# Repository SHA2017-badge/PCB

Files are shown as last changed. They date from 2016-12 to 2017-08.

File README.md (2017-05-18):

# PCB
This repository hosts the board files for the SHA2017 badge. There are a couple different revisions:
* _rev0_0_1_: First dev board
* _rev0_0_2_: First dev board with fixed IO error (not produced)
* _rev0_1_0_: "Pre-badge"
* _rev1_0_0_: Semi-final badge design - via under D3 shorts VCC to GND (oops)
* _rev1_0_1_: FINAL Badge design with short fixed and silkscreen art

The badge is designed in Eagle version 6.6.

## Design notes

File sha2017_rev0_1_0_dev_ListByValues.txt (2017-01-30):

Qty	Value	Part Num	Package	Parts
1		*	610X12243021	X2
1		68712414022	68712414022	X4
5	1k	ERJ-3GEYJ102V	R0603-DASHES	R3, R12, R14, R30, R34
9	1u	GRM188R61E105KA12D	C0603-DASHES	C18, C20, C24, C30, C31, C33, C34, C35, C36
1	2.2k	*	R0603-DASHES	R29
11	4u7/16V	GRM21BR61C475KA88K	C0805	C4, C8, C14, C16, C17, C19, C22, C25, C29, C32, C38
1	5R	ERJ-3GEYJ5R1V	R0603-DASHES	R19
18	10k	ERJ-3GEYJ103V	R0603-DASHES	R1, R4, R5, R8, R9, R10, R11, R13, R15, R16, R17, R18, R22, R25, R26, R27, R28, R33
1	22µ	NLCV32T-220K-EF	1210	L1
1	27R	*	R0603-DASHES	R2
3	100k	CRCW0603100KFKEA	R0603-DASHES	R6, R20, R31
22	100n	GRM188R71H104KA93D	C0603-DASHES	C1, C2, C3, C5, C6, C7, C9, C10, C11, C12, C13, C15, C21, C23, C26, C27, C28, C37, C39, C40, C41, C42
1	150k	*	R0603-DASHES	R32
2	220k	*	R0603-DASHES	R7, R21
2	470R	ERJ-3GEYJ103V	R0603-DASHES	R23, R24
2	500mA	0ZCJ0025FF2E	PTC-1206	F1, F2
1	2908-05WB-MG	2908-05WB-MG	MICRO-SD-SOCKET-PP	X1
1	AP7215	AP7215-33YG-13	SOT89	IC2
5	BAT20JFILM	BAT20JFILM	SOD-323	D2, D3, D7, D8, D9
1	CP210X_USB_UART	CP2102-GMR	MLP28	IC1
1	CPT112	*	QFN20-3X3MM	IC6
1	ESP32WROOM32	*	ESP32MOD	IC3
5	FIDUCIAL	NAP	FIDUCIAL_1MM	FD1, FD2, FD3, FD4, FD5
1	FXL6408	*	UMLP-16	IC5
1	JST-PH3	*	JST-PH3	X3
2	JUMPER-PAD-2-NOYES_SILK	NAP	PAD-JUMPER-2-NO_YES_SILK	SJ1, SJ2
1	MCP73833	*	MSOP-10	IC4
5	MMBT2222A	BC817-25,215	SOT23-3	Q2, Q3, Q4, Q5, Q7
1	MOLEX-47346-0001	10118194-0001LF	MOLEX-47364-0001	USB1
1	MOTOR10MM	*	VIBE-MOTOR-10MM	U$1
1	PMEG4005EJ	SD05-7	SOD-323	D1
1	RED	*	LED-0603	D5
1	SI1304 BDL	SI1308EDL-T1-GE3	SOT323	Q6
3	SI2301DS	*	SOT23	T1, T2, T3
6	SK6812	SK6812	WS2812B	D100, D101, D102, D103, D104, D105
2	SWITCH-MOMENTARY-2SMD	*	TACTILE-SWITCH-SMD	S1, S2
43	TEST-POINT3	NAP	PAD.03X.03	TP1, TP2, TP5, TP100, TP101, TP102, TP103, TP104, TP105, TP106, TP107, TP108, TP109, TP110, TP111, TP112, TP113, TP114, TP115, TP116, TP117, TP118, TP119, TP120, TP121, TP122, TP123, TP124, TP125, TP126, TP127, TP128, TP129, TP130, TP131, TP132, TP133, TP134, TP135, TP136, TP137, TP138, TP139
2	TOUCHROUND	NAP	TOUCH_BUTTON	TB103, TB104
2	TOUCHSELECT	NAP	TOUCH_SELECT	TB100, TB101
1	TOUCH_CROSS	NAP	TOUCH_CROSS	TB102
27	VIA	NAP	VIA	$$U$1, $$U$2, $$U$3, $$U$7, $$U$8, $$U$9, U$2, U$3, U$4, U$5, U$6, U$10, U$11, U$12, U$13, U$14, U$15, U$16, U$17, U$18, U$19, U$20, U$21, U$22, U$23, U$24, U$25
1	Yellow	*	LED-0603	D4
1	green	*	LED-0603	D6

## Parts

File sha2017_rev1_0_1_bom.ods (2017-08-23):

SHA2017 Badge BOM
 |  | rev1_0_1 | https://github.com/SHA2017-badge/PCB
 |  | Fixed C46 error
Qty per PCB | Type | Device | Value | Package | Parts
1 | ESP module | ESP32WROOM32 | ESP32WROOM32 | ESP32MOD | IC3
1 | Touch IC | MPR121QR2 | MPR121QR2 | QFN40P300X300X60-20N | U1
1 | Battery charger IC | TP4056 | TP4056 | SOP-8 | IC4
1 | Voltage regulator | AP2114H-3.3TRG1 | AP2114H-3.3TRG1 | SOT233-3 | IC2
1 | USB-Serial IC | CP210X_USB_UART | CP210X_USB_UART | MLP28 | IC1
1 | Battery connector | JST S3B-PH-SM4-TB | JST S3B-PH-SM4-TB | JST-PH3 | X4
5 | NPN transistor | TRANSISTOR_NPNMMBT2222A | MMBT2222A | SOT23-3 | Q1, Q2, Q3, Q4, Q6
3 | P-channel MOSFET | MOSFET-PCHANNEL |  | SOT23-3 | T1, T2, T3
1 | N-channel MOSFET | MOSFET-NCHANNEL2N7002PW | SI1304 BDL | SOT323 | Q5
2 | Tactile switch | SWITCH-MOMENTARY-2SMD | SWITCH-MOMENTARY-2SMD | TACTILE-SWITCH-SMD | S1, S2
1 | USB connector | MOLEX-47346-0001 | MOLEX-47346-0001 | MOLEX-47364-0001 | USB1
1 | IO Expansion header | 610X12243021 |  | 610X12243021 | X3
1 | Display socket | 68712414022 | 24 pos FPC 0.5mm SMD right angle | 68712414022 | X1
2 | PTC Fuse | PTCSMD | 1A | PTC-1206 | F1, F2
5 | Schottky diode | BAT20JFILM | NSVR0320MW2T1G | SOD-323 | D2, D3, D7, D8, D9
1 | ESD Suppressor | DIODE-SCHOTTKY-PMEG4005EJ | SD05-7 | SOD-323 | D1
1 | Red LED | LED0603 | RED | LED-0603 | D5
1 | Yellow LED | LED0603 | Yellow | LED-0603 | D4
1 | Green LED | LED0603 | green | LED-0603 | D6
1 | Inductor | INDUCTOR1210 | 47µ | L1210 | L1
23 | Capacitor | C0603 | 100n | C0603 | C1, C2, C3, C4, C5, C6, C7, C8, C11, C12, C14, C22, C23, C27, C31, C37, C40, C44, C45, C10, C16, C28, C29
11 | Capacitor | C0603 | 1µ | C0603 | C19, C21, C25, C32, C33, C35, C36, C38, C39, C42, C46
12 | Capacitor | C-EUC0805 | 4.7µ / 16V | C0805 | C9, C13, C15, C17, C18, C20, C24, C26, C30, C34, C41, C43
2 | Resistor | R0603 | 1.2k | R0603 | R29, R35
5 | Resistor | R0603 | 100k | R0603 | R1, R6, R20, R31, R36
16 | Resistor | R0603 | 10k | R0603 | R4, R5, R8, R9, R10, R11, R13, R15, R16, R17, R18, R25, R27, R28, R22, R32
1 | Resistor | R1206 | 0.27Ω 1/4W | R1206 | R30
3 | Resistor | R0603 | 1k | R0603 | R3, R12, R14
2 | Resistor | R0603 | 220k | R0603 | R7, R21
1 | Resistor | R1206 | 27Ω | R1206 | R2
2 | Resistor | R0603 | 4k7 | R0603 | R23, R24
1 | Resistor | R0603 | 2.7Ω | R0603 | R19
1 | Resistor | R0603 | 75k 1% | R0603 | R37
0 | Resistor | R0603 | 0Ω | R0603 | R26 | ! Only populate for GD display !
110
Optional
6 | SK2812 RGBW pixels | SK6812 | SK6812-RGBW | 5050 | D100, D101, D102, D103, D104, D105
1 | Micro SD socket | 2908-05WB-MG | 2908-05WB-MG | MICRO-SD-SOCKET-PP | X2
1 | Pager motor | MOTOR10MM | MOTOR10MM | VIBE-MOTOR-10MM | M1

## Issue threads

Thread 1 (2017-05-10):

Consider porting from ESPUSB

cnlohr, 2017-05-10:
Just throwing out the idea, though I haven't gotten around to porting ESPUSB to the ESP32, I have considered it.  Any interest in adding possible hardware support to your design?  You would only need to have two adjacent GPIO pins to add support.

gavanfantom, 2017-05-11:
That's a neat idea but unfortunately we're so close to the event now that we have had to feature-freeze the PCB already.

We do however have quite a lot of software work that needs doing between now and the end of July and while we do have a few people on the team, another person who is as familiar with the ESP32 as you are would be a real advantage. Would you be interested in lending a hand?

cnlohr, 2017-05-11:
Aah, gotcha.  Things are kinda insane for me, right now since I'm co-chairing MAGStock and that's June 8-11 then I have to worry about badges for MAGLabs (I think they're '8266 because of the stringent price requirements).  I will consider it after MAGStock though.

annejan, 2017-05-11:
Hi @cnlohr the adjacent IO16 and IO17 pins (as well as 12, 14 and 33, 3.3V and GND) are accessible through the expansion header :)
So using ESPUSB should be possible as-is . . right?

NiklasFauth, 2017-05-11:
I don't think ESPUSB is ported for the ESP32 yet. Shouldn't be a problem through.

cnlohr, 2017-05-11:
Hmm, I could see having a connector for it.  Would need a pull-up.  I have really wanted to develop full-speed USB 1.1 for the ESP32 for a while since I think it's possible.

van-cahall, 2017-05-31:
I'm not familiar with this badge, but ESPUSB for the ESP32 would be awesome!  USB is the only thing missing from the ESP32 for several killer projects I'd like to do.  +1

cnlohr, 2017-05-31:
Ughhhh.. I'm doing MAGStock prep now.  I think I'm going to put libsurvive on the backburner to give a stab at full-speed USB on the 32.

Low-speed "should" be a trivial change from the '8266.

zoutepopcorn, 2017-06-18:
Great job cnlohr :D.

cnlohr, 2017-06-19:
I'm actually doing a totally different approach ATM, but it's going well.  I would much rather get full-speed working over simply switching around low-speed.

nissimzur, 2017-07-01:
Can someone point me to SHA2017-badge schematics diagram?

annejan, 2017-07-01:
It's in this repository . .
https://github.com/SHA2017-badge/PCB/blob/master/sha2017_rev1_0_1_schematic.pdf should probably be what you are looking for.

nissimzur, 2017-07-01:
Thank you.

I offering my help in any hardware challenge you have around ESP8266/ESP32.

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

Closed 2017-05-11.

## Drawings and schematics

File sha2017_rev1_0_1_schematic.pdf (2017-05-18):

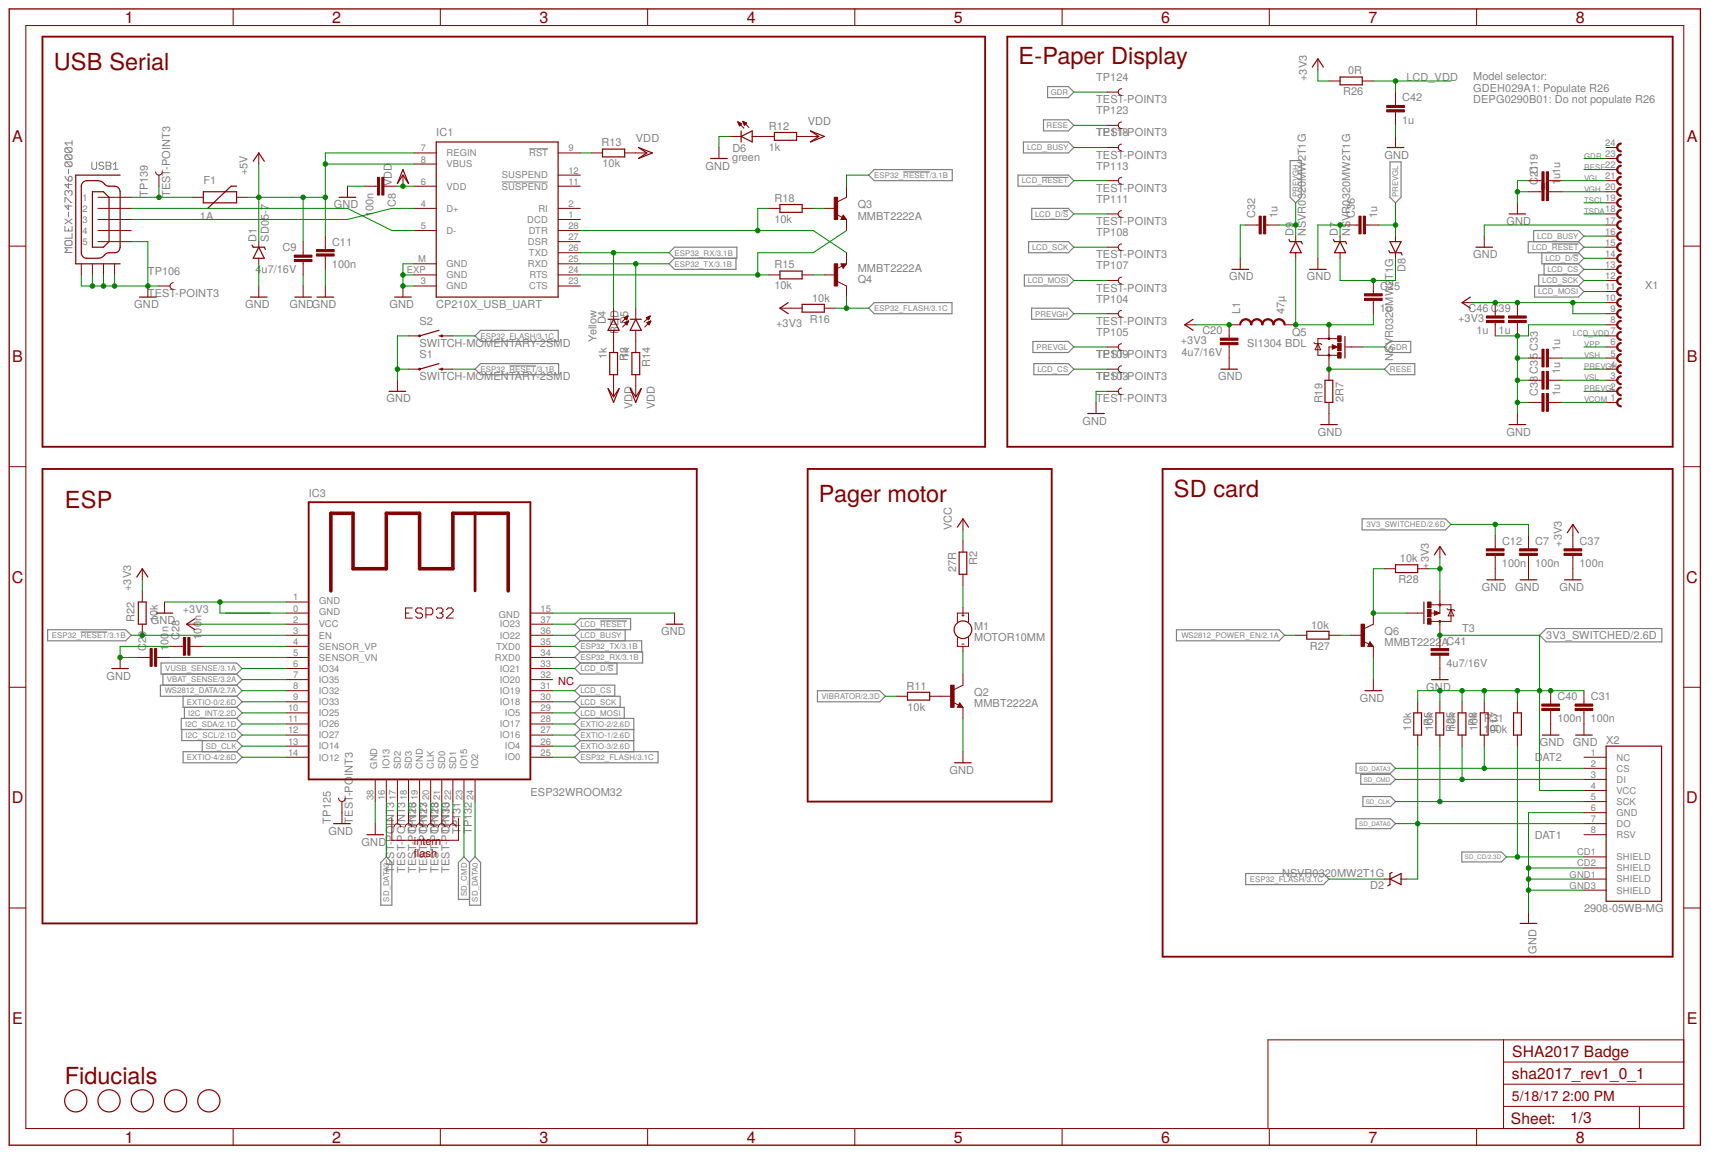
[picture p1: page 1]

+3V3 GND
TEST-POINT3 TEST-POINT3 TEST-POINT3 TEST-POINT3 TEST-POINT3 TEST-POINT3 TEST-POINT3 TEST-POINT3 TEST-POINT3 TEST-POINT3 TEST-POINT3 GND

Model selector: GDEH029A1: Populate R26 DEPG0290B01: Do not populate R26

TEST-POINT3 TEST-POINT3 TEST-POINT3 TEST-POINT3 TEST-POINT3 TEST-POINT3 TEST-POINT3 GND

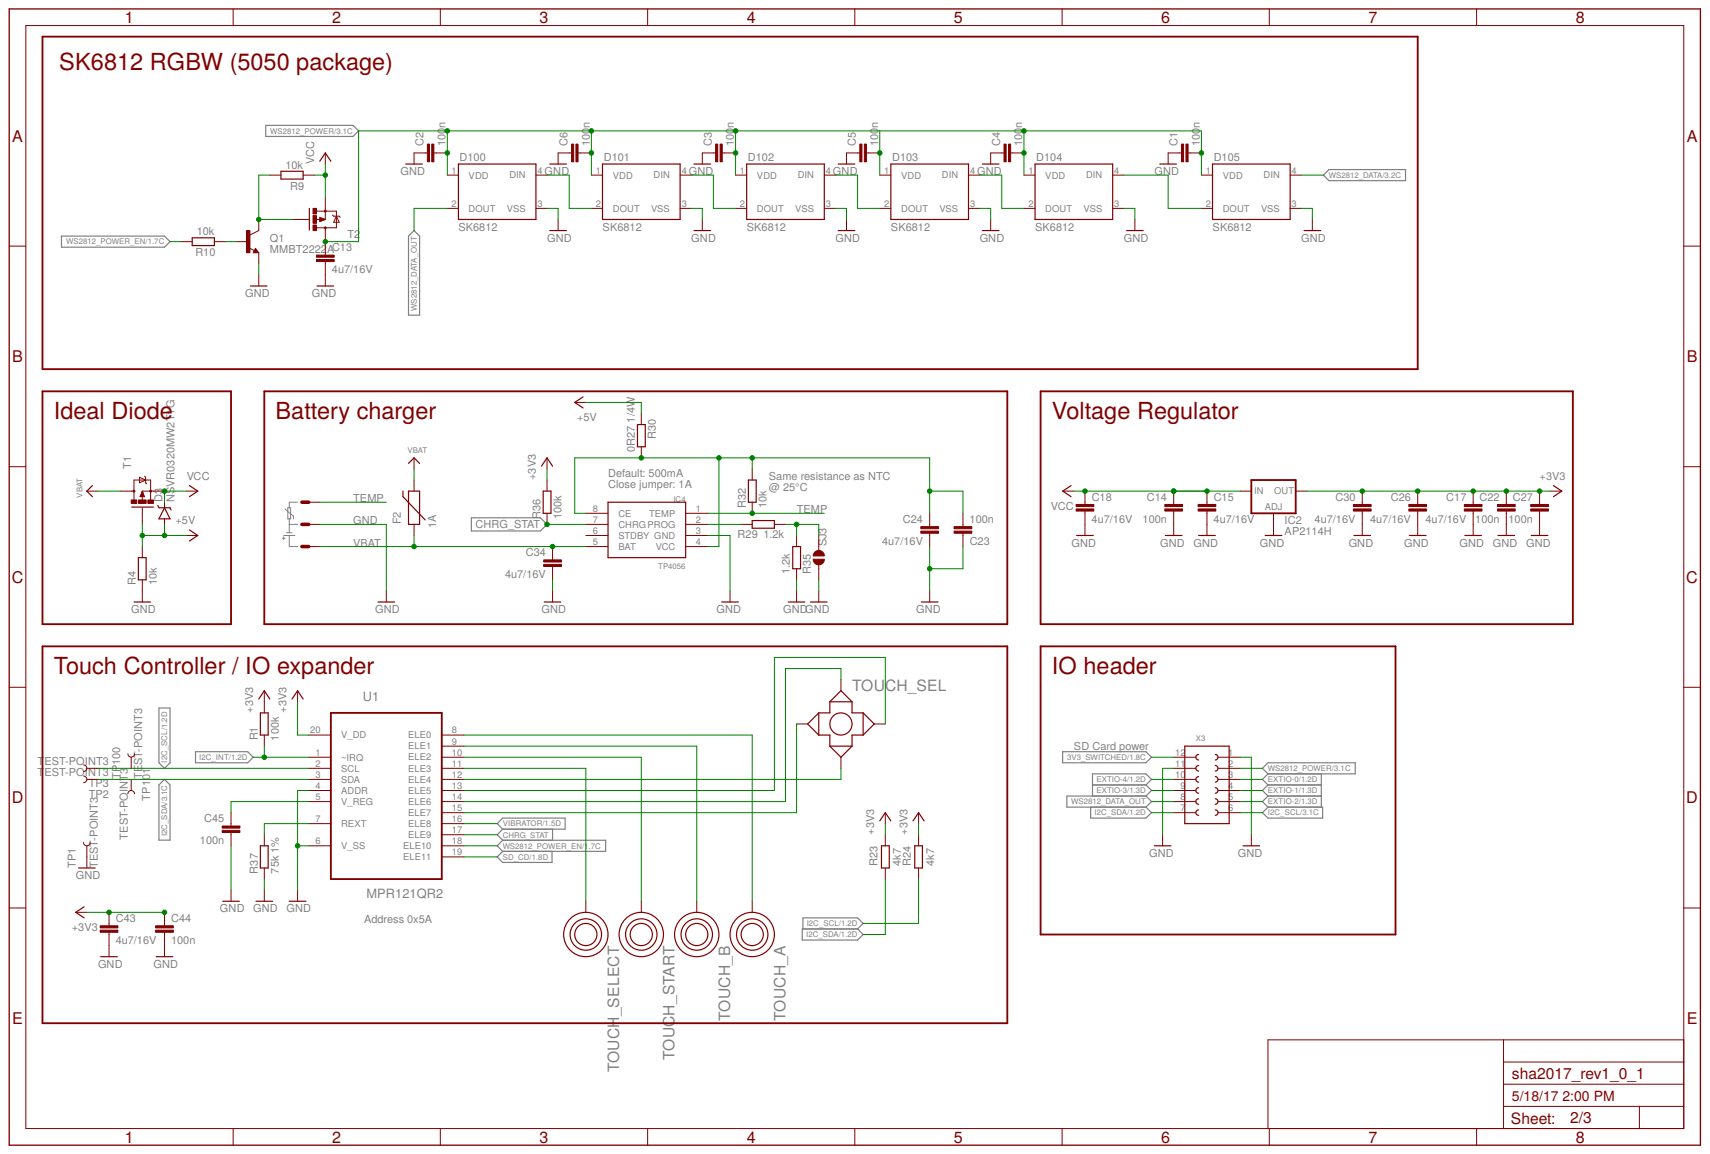
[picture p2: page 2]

Default: 500mA Close jumper: 1A GND
IN OUT C18 F2
TEMP

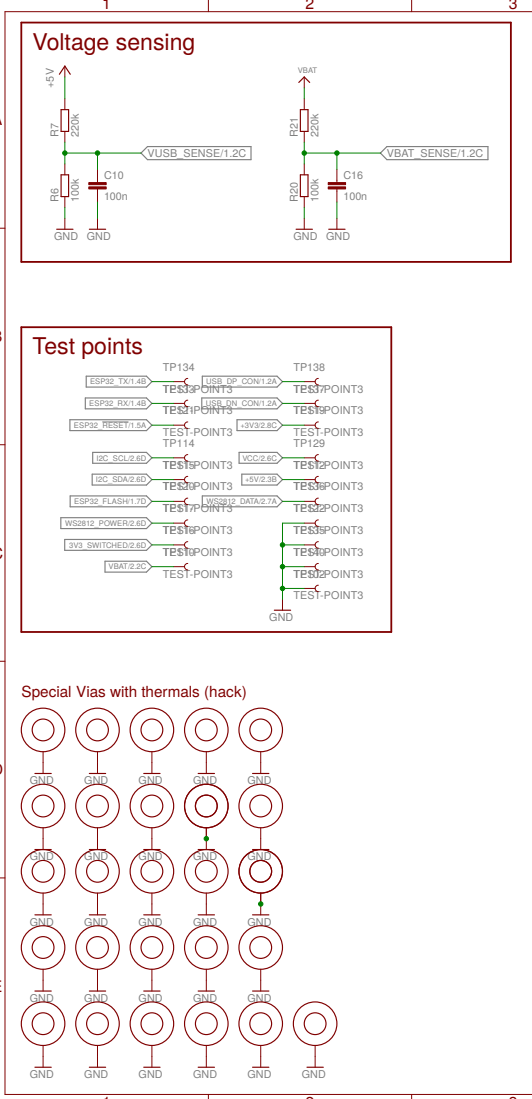
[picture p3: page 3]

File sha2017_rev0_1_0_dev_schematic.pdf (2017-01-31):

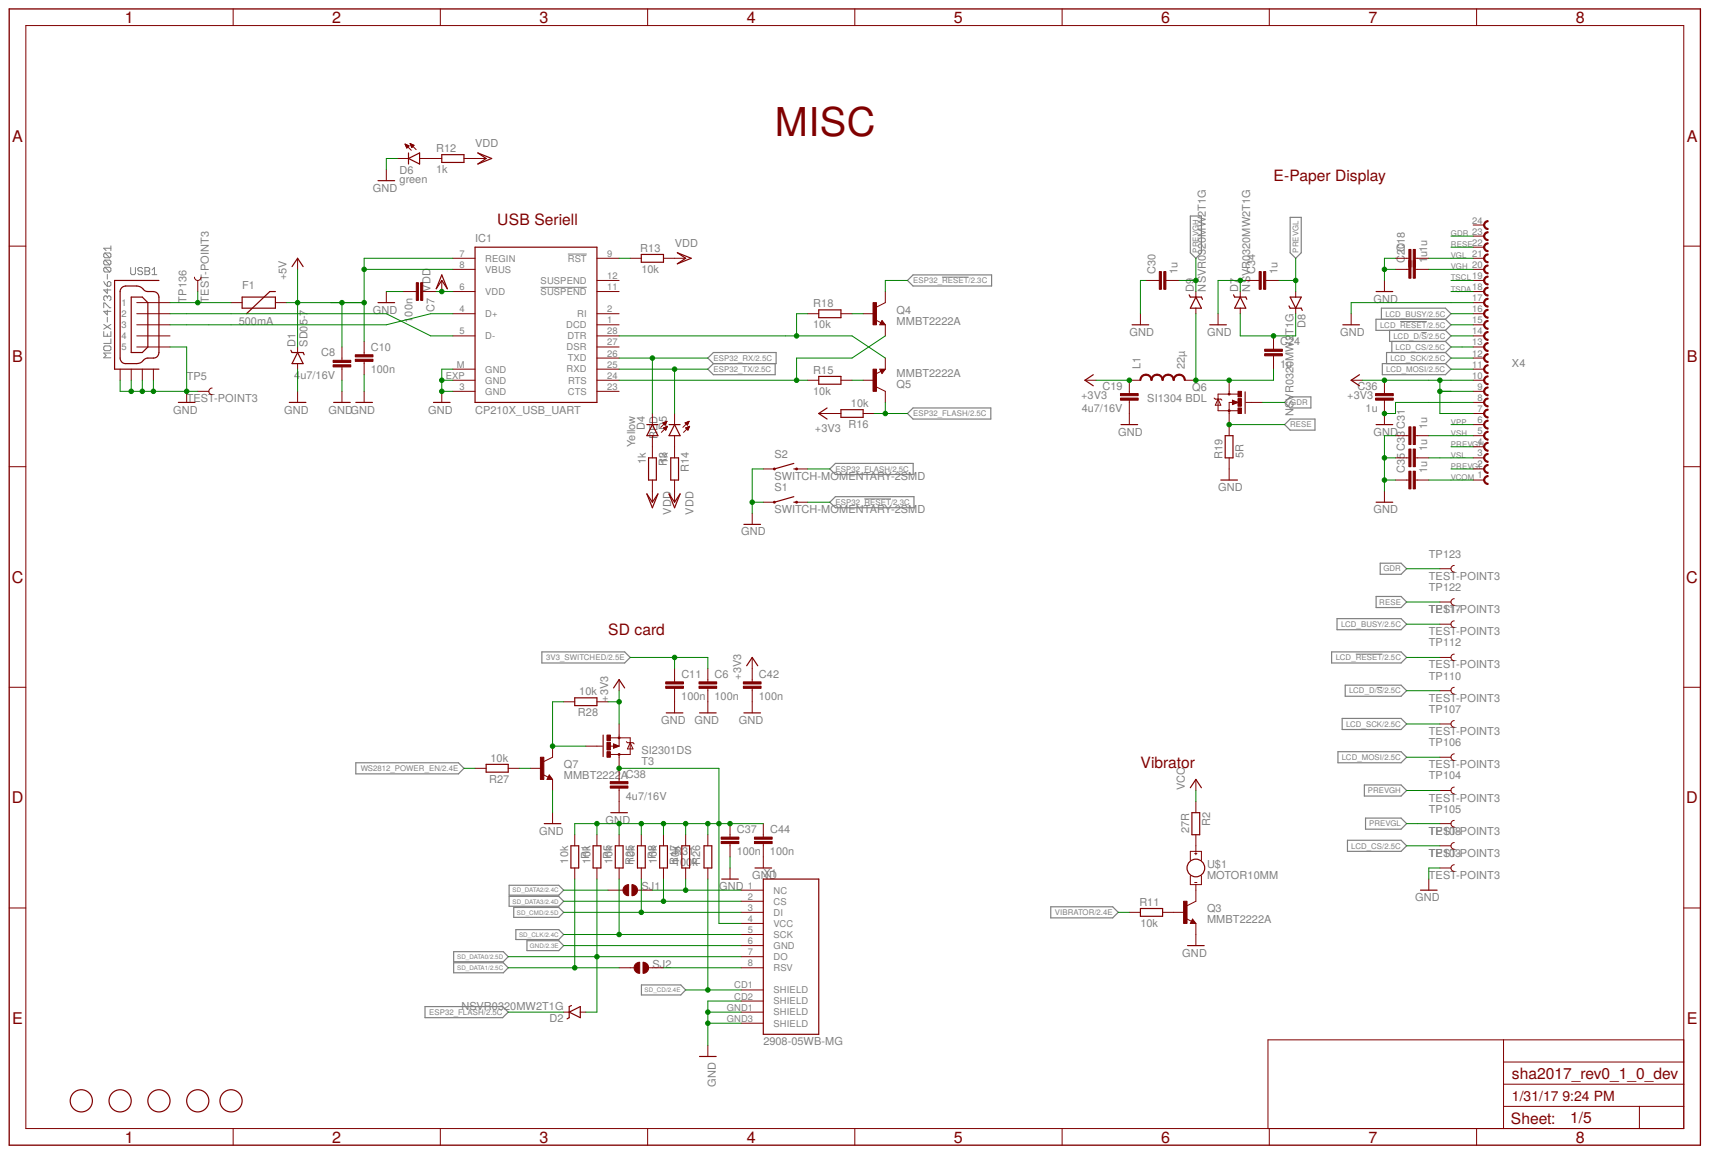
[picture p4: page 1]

SD_DATA0/2.5D | SJ2

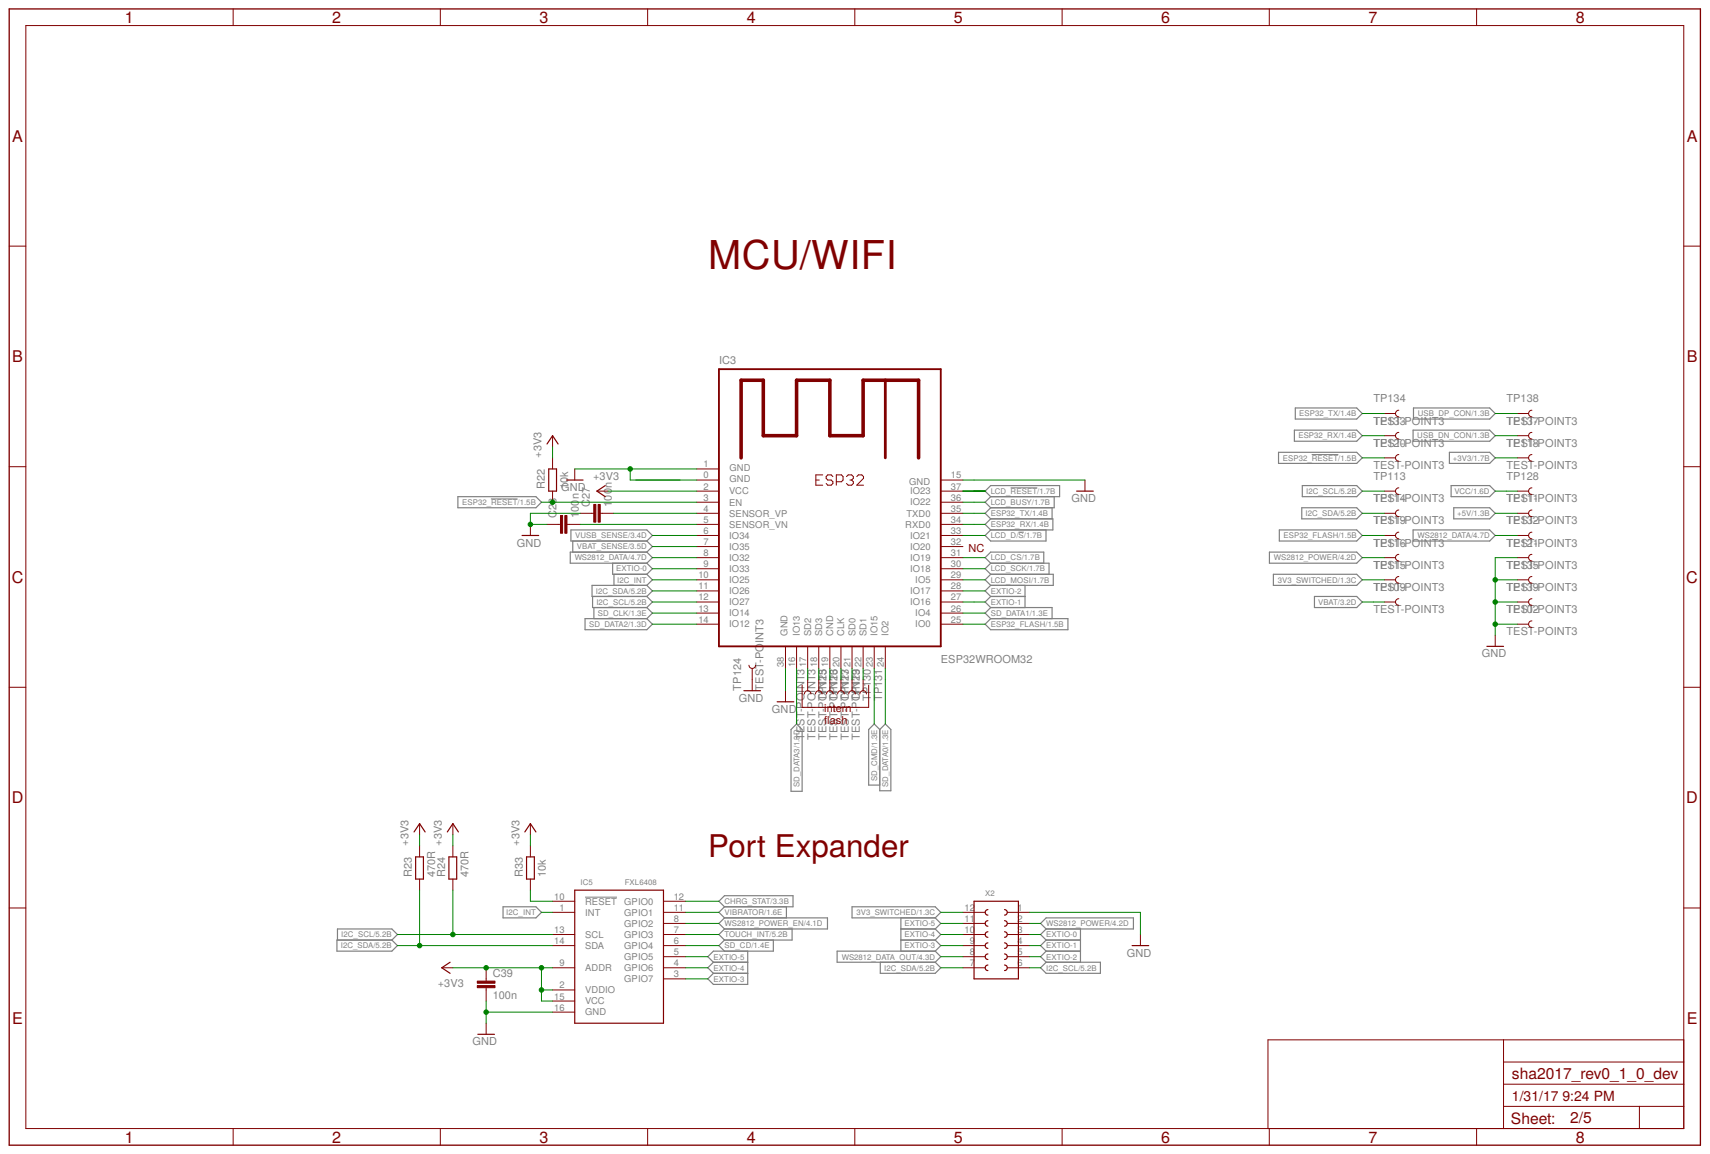
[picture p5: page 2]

TEST-POINT3 TEST-POINT3 TEST-POINT3 TEST-POINT3 TEST-POINT3 GND

TEST-POINT3 TEST-POINT3 TEST-POINT3

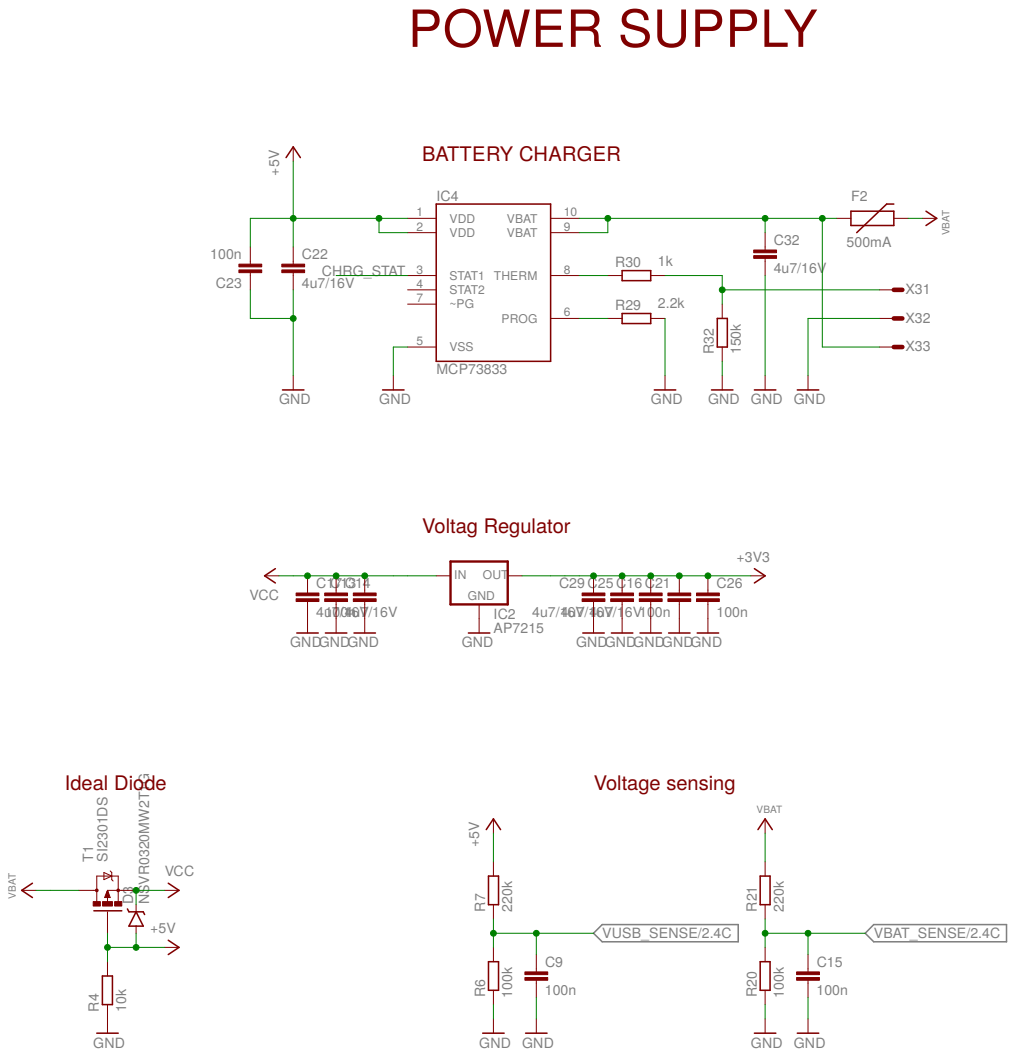
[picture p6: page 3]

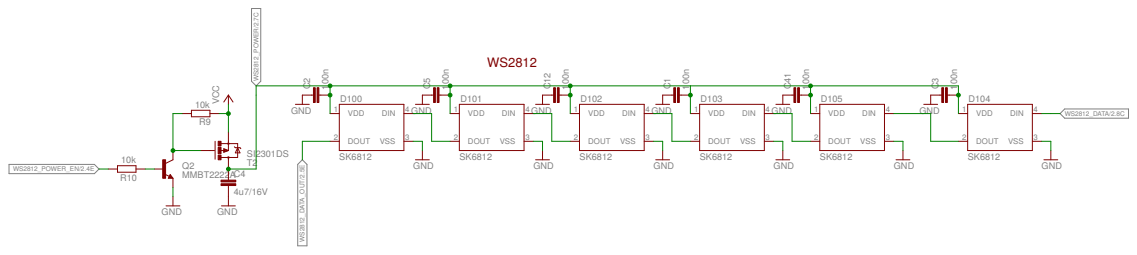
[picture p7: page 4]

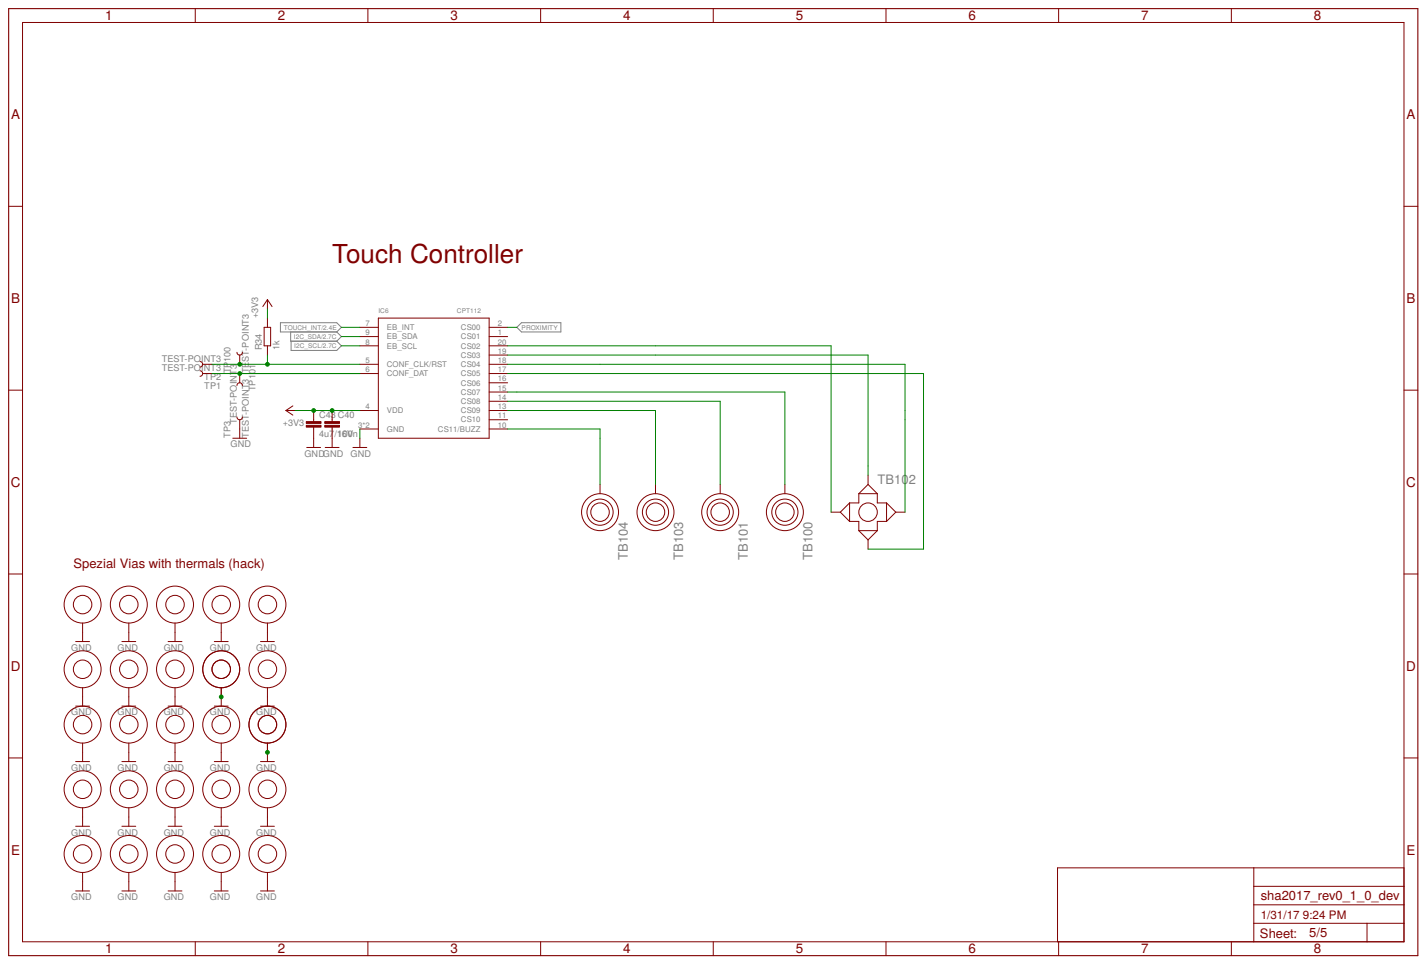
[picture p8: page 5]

TEST-POINT3 TEST-POINT3 TEST-POINT3 GND

18 CS05
17 CS06
16 CS07 15 CS08

Spezial Vias with thermals (hack)

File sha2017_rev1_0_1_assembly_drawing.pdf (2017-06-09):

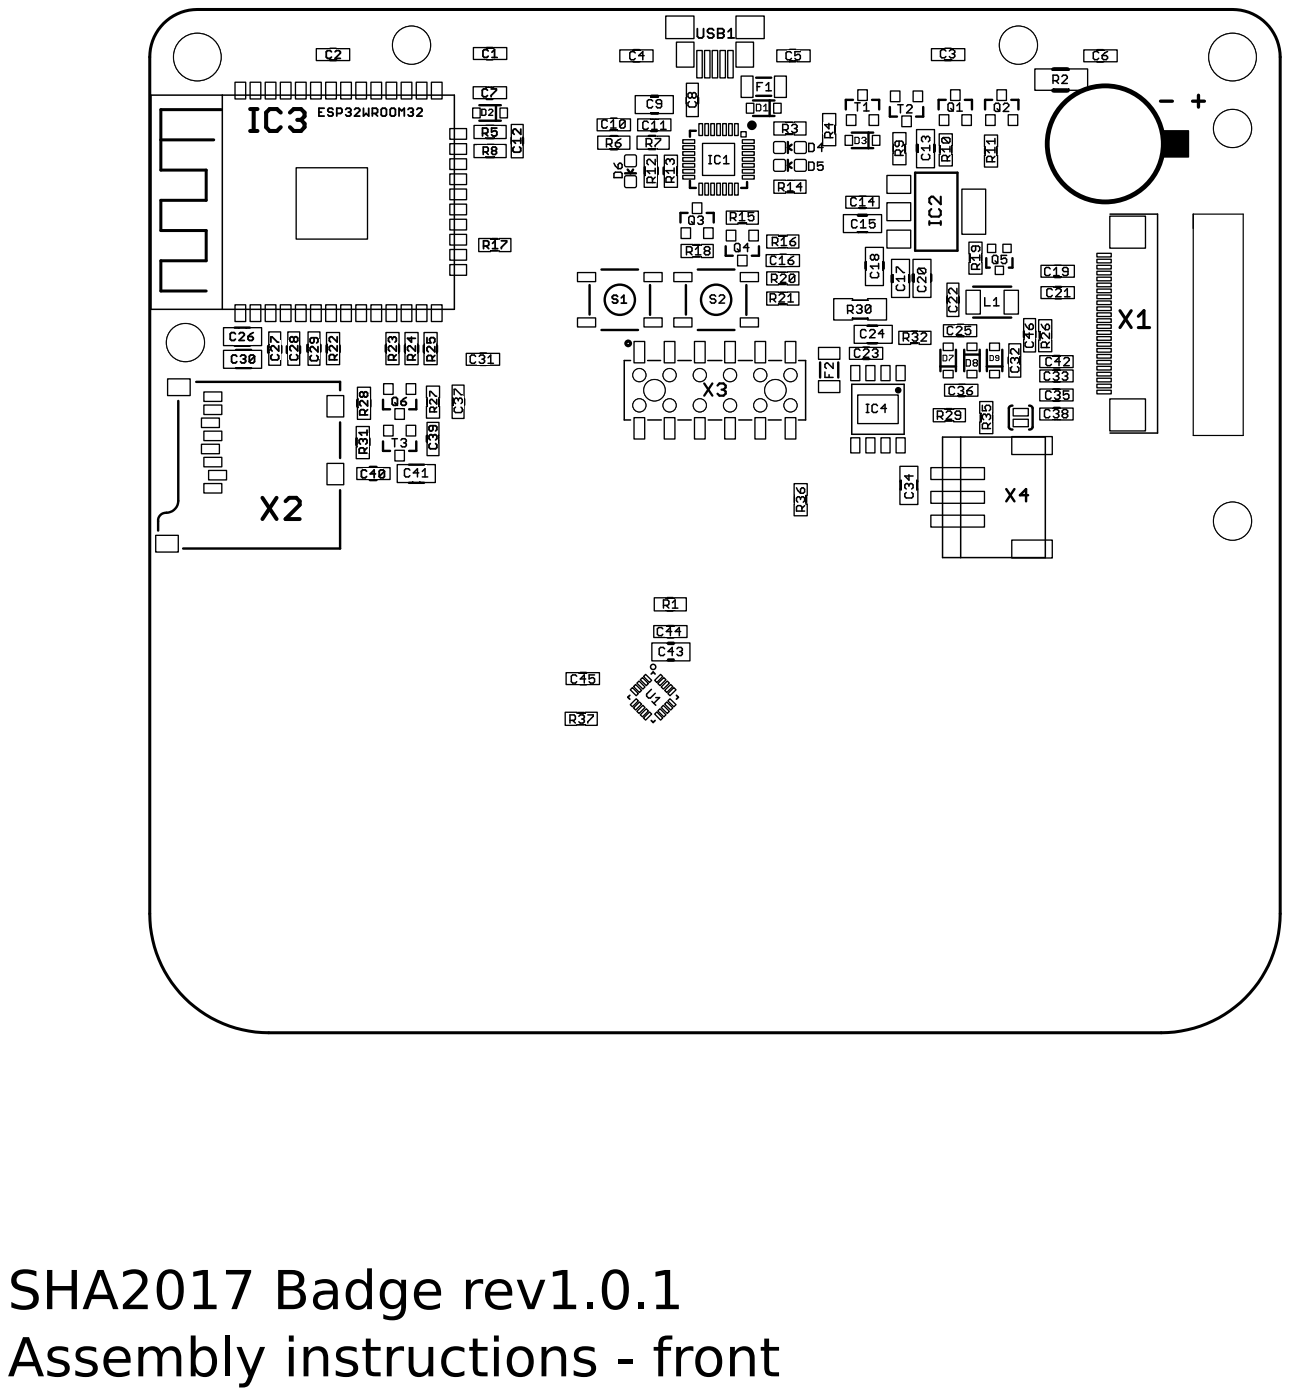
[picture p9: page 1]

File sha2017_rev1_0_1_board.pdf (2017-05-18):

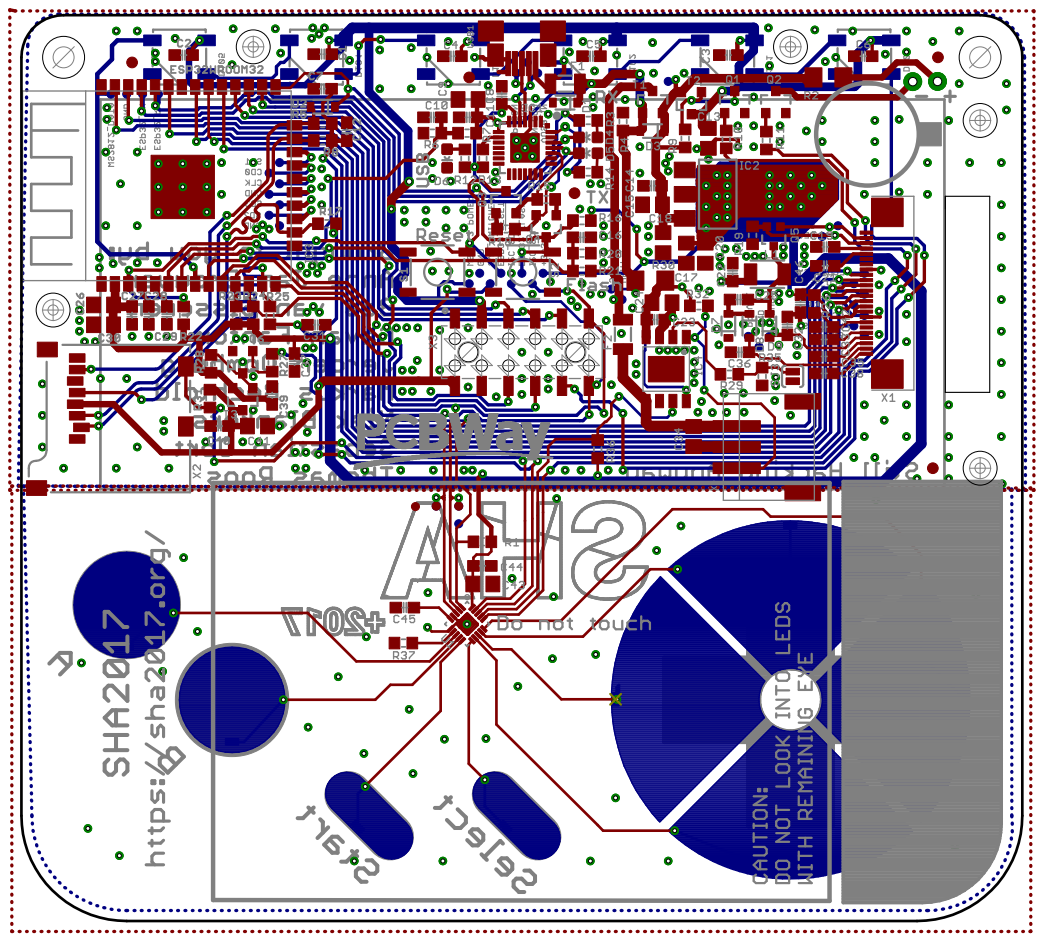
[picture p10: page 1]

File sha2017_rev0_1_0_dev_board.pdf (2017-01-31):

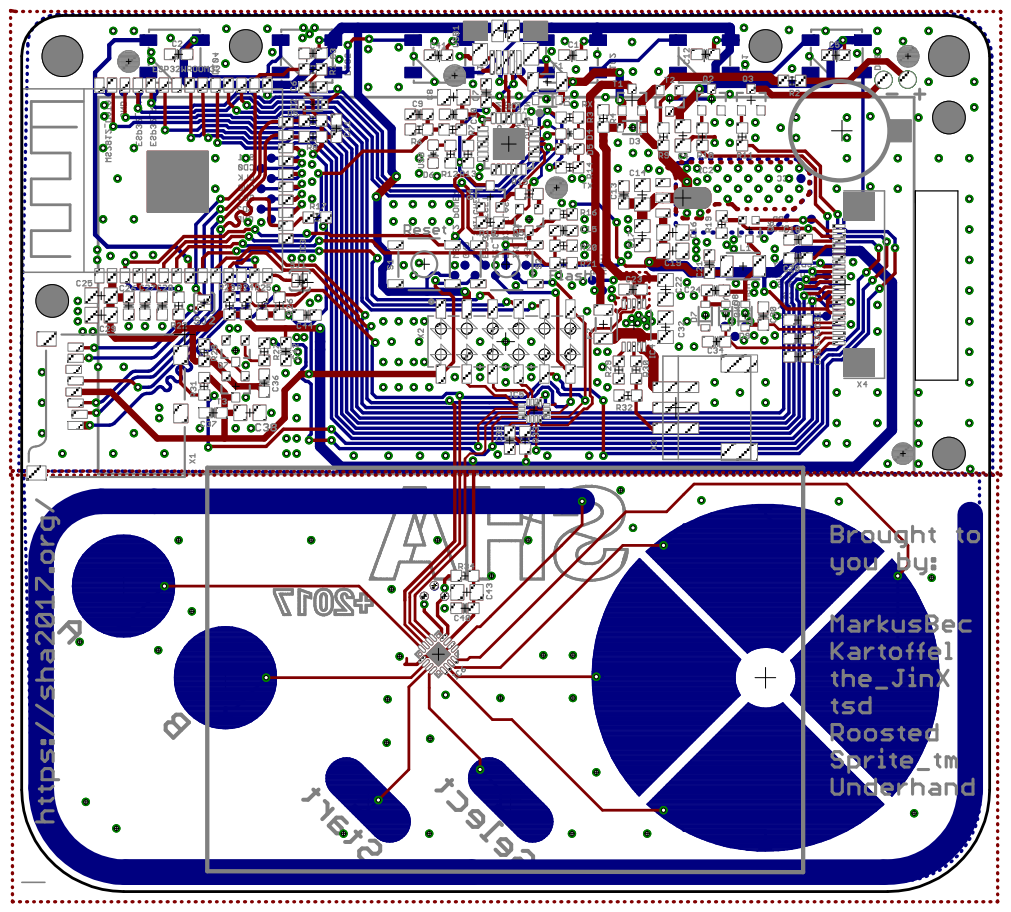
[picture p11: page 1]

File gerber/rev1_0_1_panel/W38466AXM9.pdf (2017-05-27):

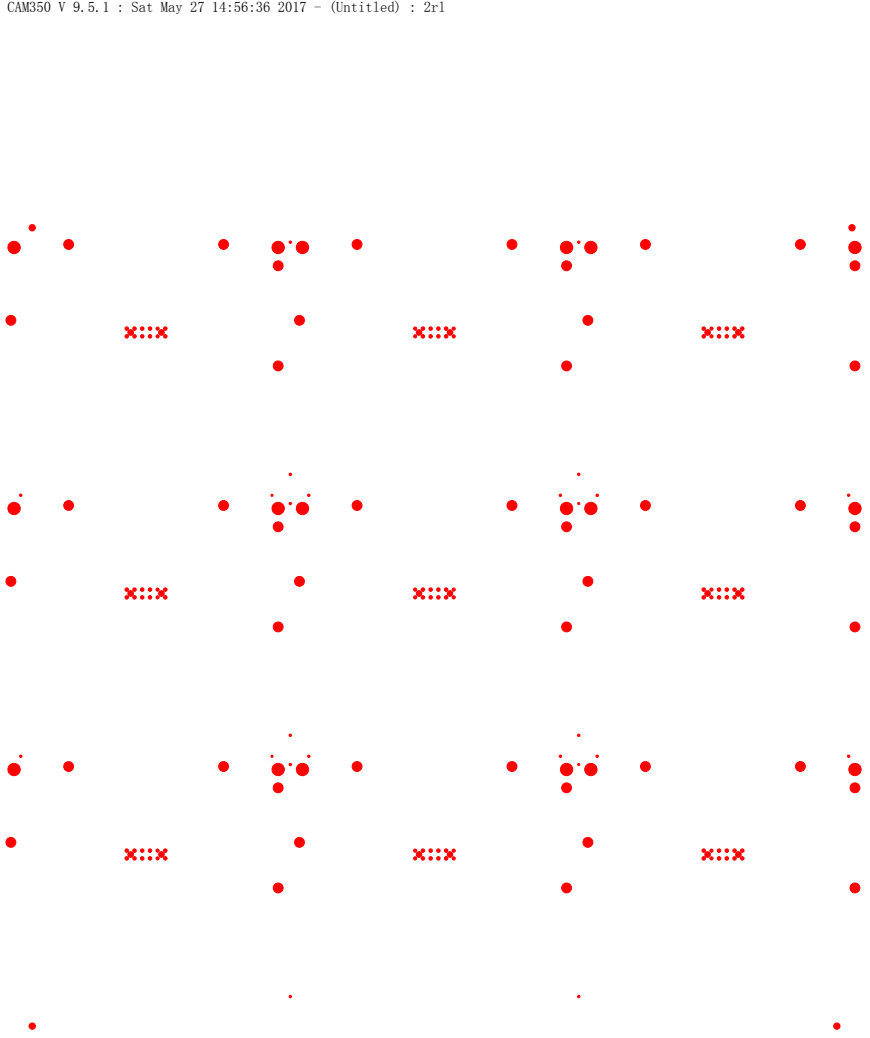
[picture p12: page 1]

CAM350 V 9.5.1 : Sat May 27 14:56:36 2017 - (Untitled) : 2rl


CAM350 V 9.5.1 : Sat May 27 14:56:37 2017 - (Untitled) : bl


CAM350 V 9.5.1 : Sat May 27 14:56:37 2017 - (Untitled) : bo


CAM350 V 9.5.1 : Sat May 27 14:56:37 2017 - (Untitled) : bs


CAM350 V 9.5.1 : Sat May 27 14:56:37 2017 - (Untitled) : drl


CAM350 V 9.5.1 : Sat May 27 14:56:37 2017 - (Untitled) : ko


CAM350 V 9.5.1 : Sat May 27 14:56:37 2017 - (Untitled) : tl


CAM350 V 9.5.1 : Sat May 27 14:56:37 2017 - (Untitled) : to


CAM350 V 9.5.1 : Sat May 27 14:56:37 2017 - (Untitled) : ts

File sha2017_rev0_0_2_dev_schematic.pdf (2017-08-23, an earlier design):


15-07-17 15:47 f=0.70 /home/bas/git/SHA2017-badge/PCB/sha2017_rev0_0_2_dev.sch (Sheet: 1/3)


7 8 6 9
5 10 4 11

15-07-17 15:47 f=0.70 /home/bas/git/SHA2017-badge/PCB/sha2017_rev0_0_2_dev.sch (Sheet: 2/3)


15-07-17 15:47 f=0.70 /home/bas/git/SHA2017-badge/PCB/sha2017_rev0_0_2_dev.sch (Sheet: 3/3)

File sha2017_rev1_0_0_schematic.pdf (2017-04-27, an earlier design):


TEST-POINT3 TEST-POINT3 TEST-POINT3 TEST-POINT3 TEST-POINT3 TEST-POINT3 TEST-POINT3 TEST-POINT3 TEST-POINT3 TEST-POINT3 TEST-POINT3 GND

TEST-POINT3 TEST-POINT3 TEST-POINT3 TEST-POINT3 TEST-POINT3 TEST-POINT3 TEST-POINT3 GND


Default: 500mA Close jumper: 1A GND
IN OUT C18 F2
TEMP



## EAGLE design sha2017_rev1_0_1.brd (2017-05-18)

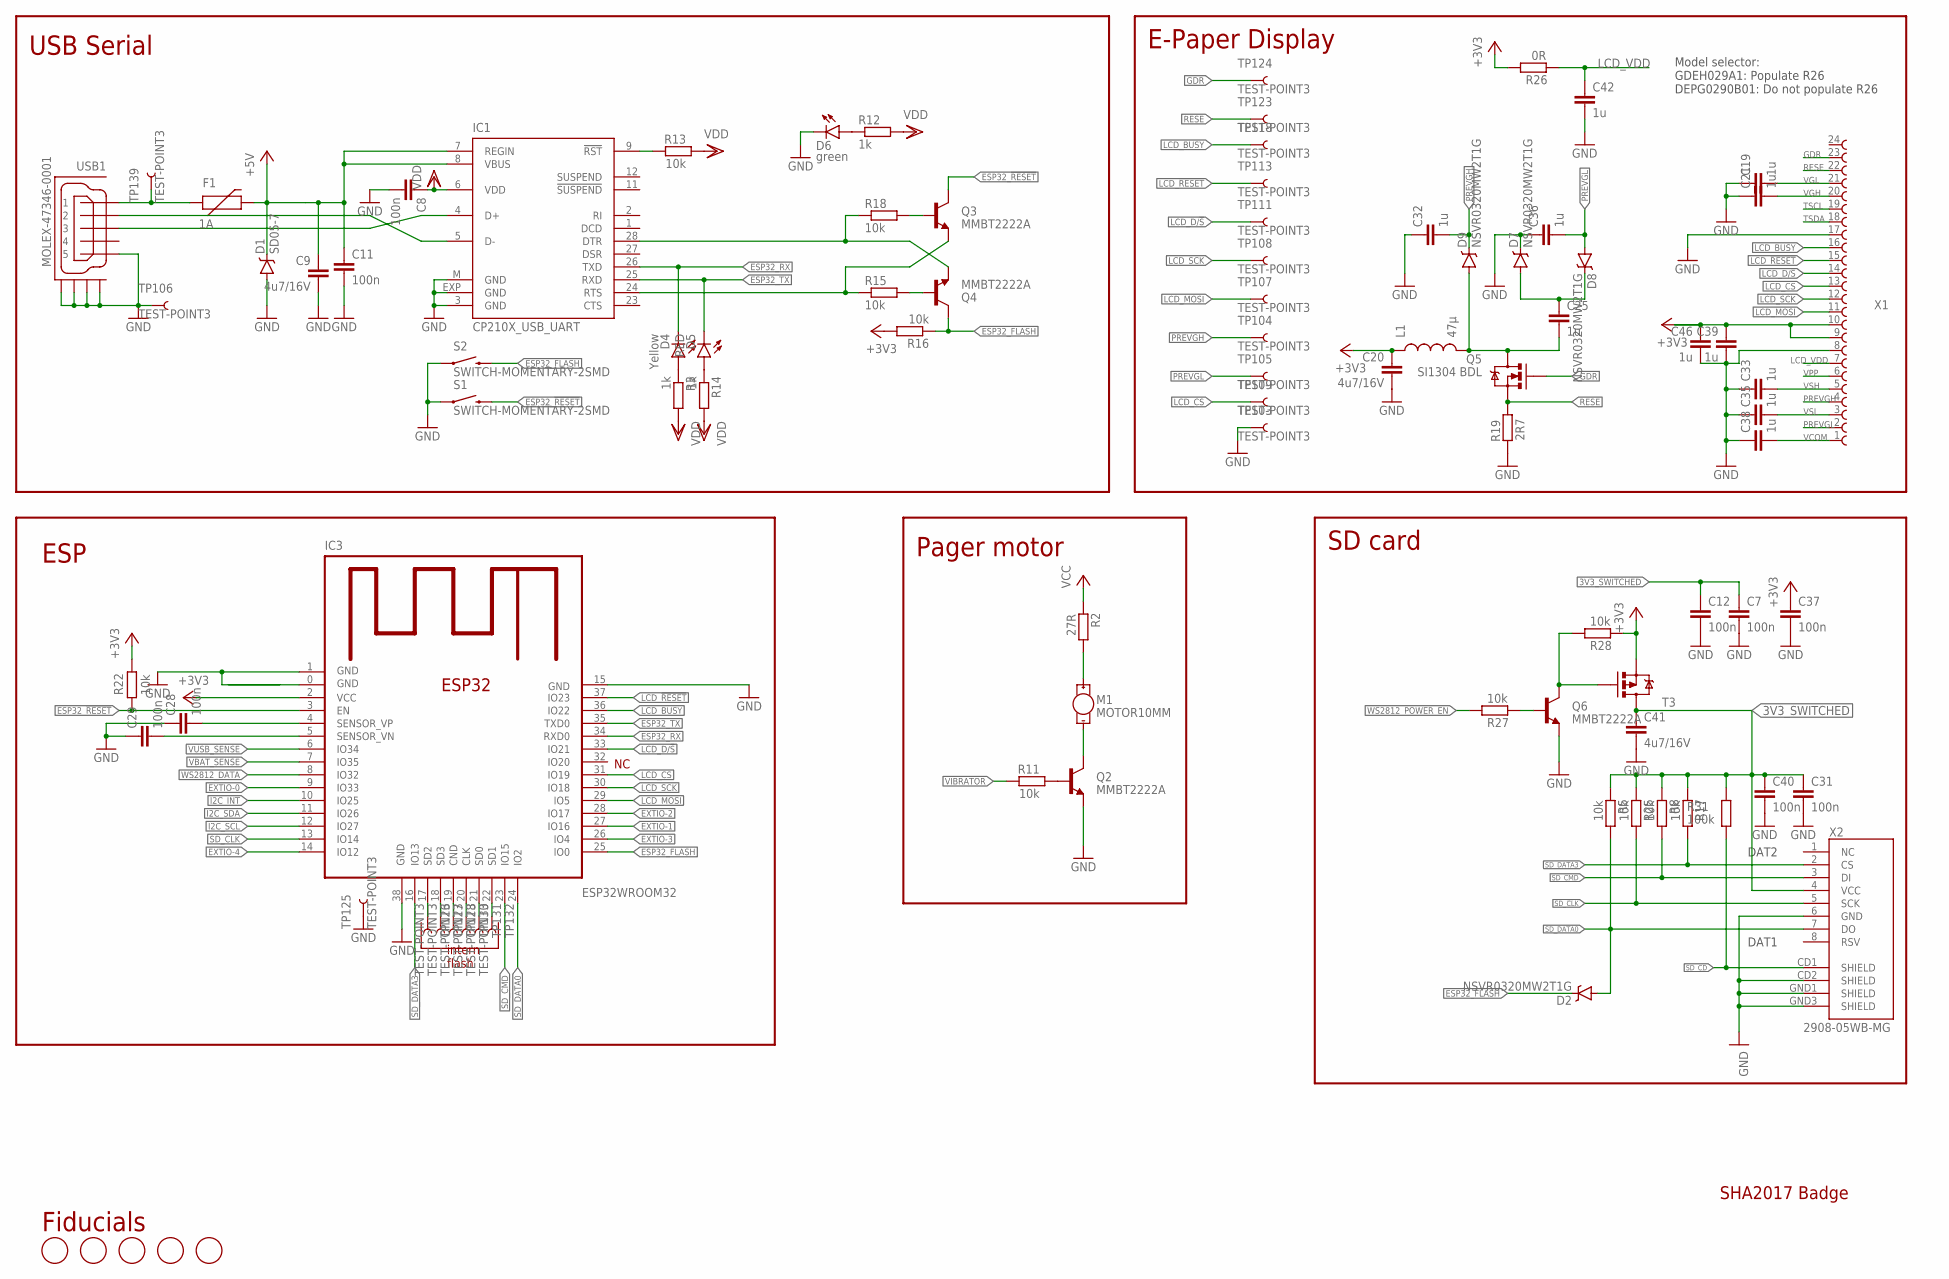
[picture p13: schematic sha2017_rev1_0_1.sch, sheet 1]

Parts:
C7, C8, C11, C12, C28, C29, C31, C37, C40: 100n; C0603-DASHES; PARTNO GRM188R71H104KA93D
C9, C20, C41: 4u7/16V; C0805; PARTNO GRM21BR61C475KA88K
C19, C21, C25, C32, C33, C35, C36, C38, C39, C42, C46: 1u; C0603-DASHES; PARTNO GRM188R61E105KA12D
D1: SD05-7; SOD-323; PARTNO SD05-7
D2, D7, D8, D9: NSVR0320MW2T1G; SOD-323; PARTNO BAT20JFILM
D4: Yellow; LED-0603
D5: RED; LED-0603
D6: green; LED-0603
F1: 1A; PTC-1206
FD1, FD2, FD3, FD4, FD5: FIDUCIAL; FIDUCIAL_1MM; PARTNO NAP
IC1: CP210X_USB_UART; MLP28; PARTNO CP2102-GMR
IC3: ESP32WROOM32; ESP32MOD
L1: 47µ; 1210; PARTNO NLCV32T-220K-EF
M1: MOTOR10MM; VIBE-MOTOR-10MM
Q2, Q3, Q4, Q6: MMBT2222A; SOT23-3; PARTNO BC817-25,215
Q5: SI1304 BDL; SOT323; PARTNO SI1308EDL-T1-GE3
R2: 27R; R1206; PARTNO ERJ-3GEYJ220V
R3, R12, R14: 1k; R0603-DASHES; PARTNO ERJ-3GEYJ102V
R5, R8, R11, R13, R15, R16, R17, R18, R22, R25, R27, R28: 10k; R0603-DASHES; PARTNO ERJ-3GEYJ103V
R19: 2R7; R0603-DASHES; PARTNO ERJ-3GEYJ5R1V
R26: 0R; R0603-DASHES; PARTNO ERJ-3GEYJ5R1V
R31: 100k; R0603-DASHES; PARTNO ERJ-3GEYJ104V
S1, S2: SWITCH-MOMENTARY-2SMD; TACTILE-SWITCH-SMD; PARTNO SKQGABE010
T3: MOSFET-PCHANNEL; SOT23-3
TP103, TP104, TP105, TP106, TP107, TP108, TP109, TP111, TP113, TP118, TP123, TP124, TP125, TP126, TP127, TP128, TP130, TP131, TP132, TP139: TEST-POINT3; PAD.03X.03; PARTNO NAP
USB1: MOLEX-47346-0001; MOLEX-47364-0001; PARTNO 10118192-0001LF
X1: 68712414022; PARTNO 68712414022
X2: 2908-05WB-MG; MICRO-SD-SOCKET-PP; PARTNO 2908-05WB-MG

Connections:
3V3_SWITCHED: C7.1, C12.1, C31.1, C40.1, C41.1, R5.2, R8.2, R17.2, R25.2, R31.1, T3.3 (D), X2.4 (VCC); also elsewhere on the board
+3V3: C20.1, C37.1, C39.1, C46.1, IC3.2 (VCC), L1.1, R16.2, R22.1, R26.1, R28.2, T3.2 (S), X1.9, X1.10; also elsewhere on the board
+5V: C9.1, C11.1, D1.C, F1.2, IC1.7 (REGIN), IC1.8 (VBUS); also elsewhere on the board
CD0: IC3.21 (SD0), TP131.P$1
CLK: IC3.20 (CLK), TP130.P$1
CND: IC3.19 (CND), TP128.P$1
ESP32_!RESET: IC3.3 (EN), Q3.3 (C), R22.2, S1.3 (2); also elsewhere on the board
ESP32_FLASH: D2.C, IC3.25 (IO0), Q4.3 (C), R16.1, S2.3 (2); also elsewhere on the board
ESP32_RX: D4.C, IC1.26 (TXD), IC3.34 (RXD0); also elsewhere on the board
ESP32_TX: D5.C, IC1.25 (RXD), IC3.35 (TXD0); also elsewhere on the board
EXTIO-0: IC3.9 (IO33); also elsewhere on the board
EXTIO-1: IC3.27 (IO16); also elsewhere on the board
EXTIO-2: IC3.28 (IO17); also elsewhere on the board
EXTIO-3: IC3.26 (IO4); also elsewhere on the board
EXTIO-4: IC3.14 (IO12); also elsewhere on the board
GDR: Q5.1 (G), TP124.P$1, X1.23
GND: C7.2, C8.2, C9.2, C11.2, C12.2, C19.1, C20.2, C21.1, C28.1, C29.1, C31.2, C32.1, C33.1, C35.1, C36.1, C37.2, C38.1, C39.2, C40.2, C41.2, C42.2, C46.2, D1.A, D6.C, D7.C, IC1.3 (GND), IC1.EXP (GND), IC1.M (GND), IC3.0 (GND), IC3.1 (GND), IC3.15 (GND), IC3.38 (GND), Q2.2 (E), Q6.2 (E), R19.2, S1.1, S2.1, TP103.P$1, TP106.P$1, TP125.P$1, USB1.5, USB1.GND1, USB1.GND2, USB1.GND3, USB1.GND4, X1.8, X1.17, X2.6 (GND), X2.CD2 (SHIELD), X2.GND1 (SHIELD), X2.GND3 (SHIELD); also elsewhere on the board
I2C_INT: IC3.10 (IO25); also elsewhere on the board
I2C_SCL: IC3.12 (IO27); also elsewhere on the board
I2C_SDA: IC3.11 (IO26); also elsewhere on the board
LCD_!RESET: IC3.37 (IO23), TP113.P$1, X1.15
LCD_BUSY: IC3.36 (IO22), TP118.P$1, X1.16
LCD_CS: IC3.31 (IO19), TP109.P$1, X1.13
LCD_D/!S: IC3.33 (IO21), TP111.P$1, X1.14
LCD_MOSI: IC3.29 (IO5), TP107.P$1, X1.11
LCD_SCK: IC3.30 (IO18), TP108.P$1, X1.12
LCD_VDD: C42.1, R26.2, X1.7
unnamed: IC1.9 (!RST), R13.2
unnamed: IC1.24 (RTS), Q3.2 (E), R15.1
unnamed: IC1.28 (DTR), Q4.2 (E), R18.1
unnamed: Q4.1 (B), R15.2
unnamed: Q3.1 (B), R18.2
unnamed: Q6.1 (B), R27.2
unnamed: M1.-, Q2.3 (C)
unnamed: Q6.3 (C), R28.1, T3.1 (G)
unnamed: M1.+, R2.1
unnamed: C25.1, D7.A, D8.C
unnamed: C25.2, D9.A, L1.2, Q5.3 (D)
unnamed: D6.A, R12.1
unnamed: D4.A, R3.1
unnamed: D5.A, R14.1
unnamed: F1.1, TP139.P$1, USB1.1
unnamed: C28.2, IC3.4 (SENSOR_VP)
unnamed: C29.2, IC3.5 (SENSOR_VN)
unnamed: Q2.1 (B), R11.1
PREVGH: C32.2, D9.C, TP104.P$1, X1.4
PREVGL: C36.2, D8.A, TP105.P$1, X1.2
RESE: Q5.2 (S), R19.1, TP123.P$1, X1.22
SD1: IC3.22 (SD1), TP132.P$1
SD2: IC3.17 (SD2), TP126.P$1
SD3: IC3.18 (SD3), TP127.P$1
SD_CD: R31.2, X2.CD1 (SHIELD); also elsewhere on the board
SD_CLK: IC3.13 (IO14), R25.1, X2.5 (SCK)
SD_CMD: IC3.23 (IO15), R8.1, X2.3 (DI)
SD_DATA0: D2.A, IC3.24 (IO2), R5.1, X2.7 (DO)
SD_DATA3: IC3.16 (IO13), R17.1, X2.2 (CS)
TSCL: X1.19
TSDA: X1.18
USB_DN_CON: IC1.5 (D-), USB1.2; also elsewhere on the board
USB_DP_CON: IC1.4 (D+), USB1.3; also elsewhere on the board
VBAT_SENSE: IC3.7 (IO35); also elsewhere on the board
VCC: R2.2; also elsewhere on the board
VCOM: C38.2, X1.1
VDD: C8.1, IC1.6 (VDD), R3.2, R12.2, R13.1, R14.2
VGH: C21.2, X1.20
VGL: C19.2, X1.21
VIBRATOR: R11.2; also elsewhere on the board
VPP: X1.6
VSH: C33.2, X1.5
VSL: C35.2, X1.3
VUSB_SENSE: IC3.6 (IO34); also elsewhere on the board
WS2812_DATA: IC3.8 (IO32); also elsewhere on the board
WS2812_POWER_EN: R27.1; also elsewhere on the board

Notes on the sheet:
USB Serial
E-Paper Display
SD card
intern flash
ESP
Fiducials
Pager motor
DAT1
DAT2
Model selector: GDEH029A1: Populate R26 DEPG0290B01: Do not populate R26
SHA2017 Badge

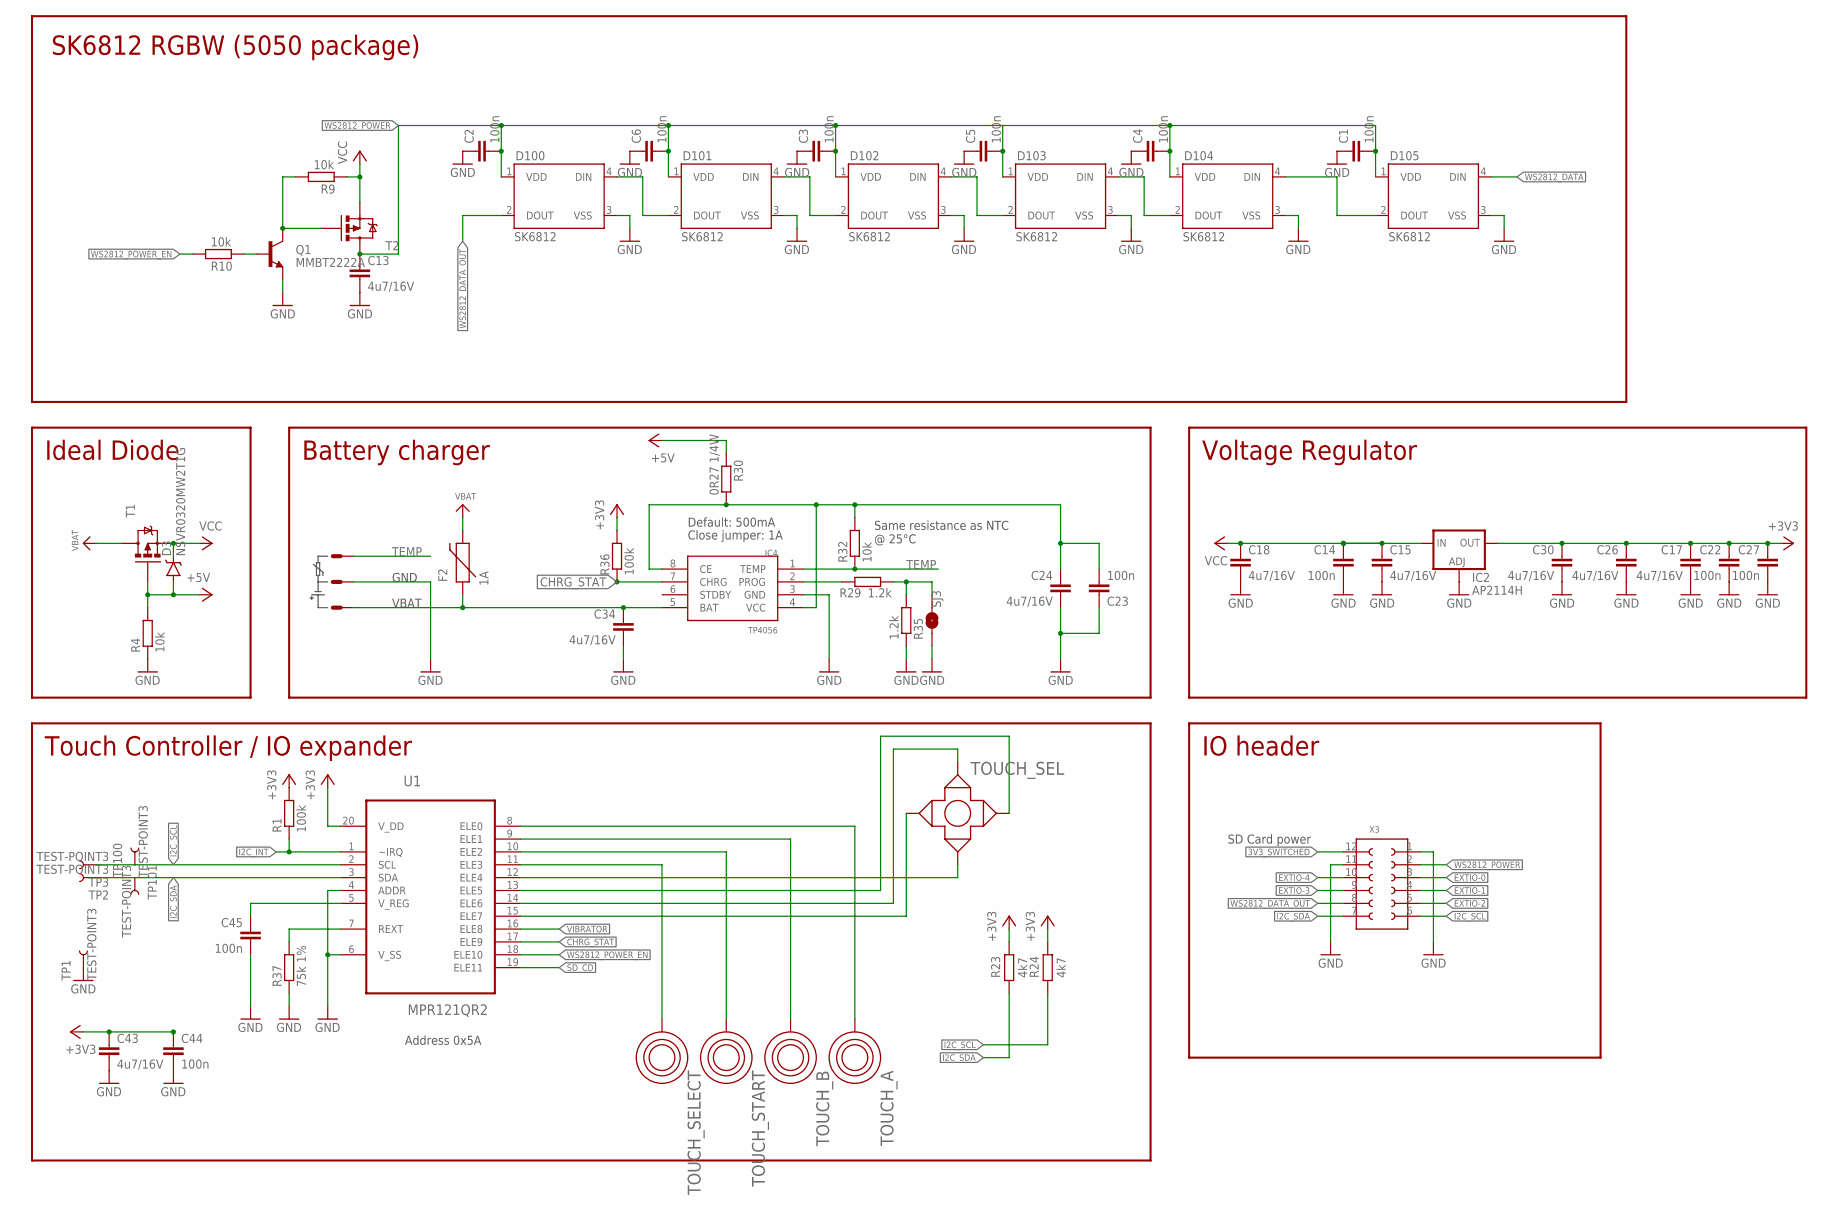
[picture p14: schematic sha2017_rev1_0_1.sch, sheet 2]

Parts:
C1, C2, C3, C4, C5, C6, C14, C22, C23, C27, C44, C45: 100n; C0603-DASHES; PARTNO GRM188R71H104KA93D
C13, C15, C17, C18, C24, C26, C30, C34, C43: 4u7/16V; C0805; PARTNO GRM21BR61C475KA88K
D3: NSVR0320MW2T1G; SOD-323; PARTNO BAT20JFILM
D100, D101, D102, D103, D104, D105: SK6812; WS2812B; PARTNO SK6812
F2: 1A; PTC-1206
IC2: AP2114H; SOT223; PARTNO AP7215-33YG-13
IC4: TP4056; SOP-8
Q1: MMBT2222A; SOT23-3; PARTNO BC817-25,215
R1, R36: 100k; R0603-DASHES; PARTNO ERJ-3GEYJ104V
R4, R9, R10: 10k; R0603-DASHES; PARTNO ERJ-3GEYJ103V
R23, R24: 4k7; R0603-DASHES; PARTNO ERJ-3GEYJ103V
R29, R35: 1.2k; R0603-DASHES; PARTNO ERJ-3GEYJ222V
R30: 0R27 1/4W; R1206; PARTNO ERJ-3GEYJ154V
R32: 10k; R0603-DASHES; PARTNO ERJ-3GEYJ154V
R37: 75k 1%; R0603-DASHES; PARTNO ERJ-3GEYJ104V
SJ3: JUMPER-PAD-2-NOYES_SILK; PAD-JUMPER-2-NO_YES_SILK; PARTNO NAP
T1, T2: MOSFET-PCHANNEL; SOT23-3
TOUCH_A: TOUCHROUND; TOUCH_BUTTON; PARTNO NAP
TOUCH_B: TOUCHROUND; TOUCH_BUTTON; PARTNO NAP
TOUCH_SEL: TOUCH_CROSS; PARTNO NAP
TOUCH_SELECT: TOUCHSELECT; TOUCH_SELECT
TOUCH_START: TOUCHSELECT; TOUCH_SELECT
TP1, TP2, TP3, TP100, TP101: TEST-POINT3; PAD.03X.03; PARTNO NAP
U1: MPR121QR2; QFN40P300X300X60-20N
X3: 610X12243021; PARTNO 517-153208-2020-TB
X4: JST-PH3

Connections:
3V3_SWITCHED: X3.12 (1); also elsewhere on the board
+3V3: C17.1, C22.1, C26.1, C27.1, C30.1, C43.1, C44.1, IC2.4 (OUT), R1.2, R23.1, R24.1, R36.2, U1.20 (V_DD); also elsewhere on the board
+5V: D3.A, R4.2, R30.1, T1.1 (G); also elsewhere on the board
CHRG_STAT: IC4.7 (CHRG), R36.1, U1.17 (ELE9)
EXTIO-0: X3.3 (10); also elsewhere on the board
EXTIO-1: X3.4 (9); also elsewhere on the board
EXTIO-2: X3.5 (8); also elsewhere on the board
EXTIO-3: X3.9 (4); also elsewhere on the board
EXTIO-4: X3.10 (3); also elsewhere on the board
GND: C1.1, C2.1, C3.1, C4.1, C5.1, C6.1, C13.2, C14.2, C15.2, C17.2, C18.2, C22.2, C23.1, C24.2, C26.2, C27.2, C30.2, C34.2, C43.2, C44.2, C45.2, D100.3 (VSS), D101.3 (VSS), D102.3 (VSS), D103.3 (VSS), D104.3 (VSS), D105.3 (VSS), IC2.1 (ADJ), IC4.3 (GND), Q1.2 (E), R4.1, R35.2, R37.1, SJ3.1, TP1.P$1, U1.4 (ADDR), U1.6 (V_SS), X3.1 (12), X3.11 (2), X4.2; also elsewhere on the board
I2C_INT: R1.1, U1.1 (~IRQ); also elsewhere on the board
I2C_SCL: R24.2, TP3.P$1, TP100.P$1, U1.2 (SCL), X3.6 (7); also elsewhere on the board
I2C_SDA: R23.2, TP2.P$1, TP101.P$1, U1.3 (SDA), X3.7 (6); also elsewhere on the board
unnamed: TOUCH_B.P$1, U1.9 (ELE1)
unnamed: D100.4 (DIN), D101.2 (DOUT)
unnamed: D103.4 (DIN), D104.2 (DOUT)
unnamed: D104.4 (DIN), D105.2 (DOUT)
unnamed: TOUCH_A.P$1, U1.8 (ELE0)
unnamed: IC4.2 (PROG), R29.1
unnamed: R29.2, R35.1, SJ3.2
unnamed: C23.2, C24.1, IC4.4 (VCC), IC4.8 (CE), R30.2, R32.2
unnamed: D101.4 (DIN), D102.2 (DOUT)
unnamed: C45.1, U1.5 (V_REG)
unnamed: R37.2, U1.7 (REXT)
unnamed: TOUCH_START.P$1, U1.10 (ELE2)
unnamed: TOUCH_SELECT.P$1, U1.11 (ELE3)
unnamed: TOUCH_SEL.D (DOWN), U1.12 (ELE4)
unnamed: TOUCH_SEL.L (LEFT), U1.15 (ELE7)
unnamed: TOUCH_SEL.UP, U1.14 (ELE6)
unnamed: TOUCH_SEL.R (RIGHT), U1.13 (ELE5)
unnamed: C34.1, F2.1, IC4.5 (BAT), X4.3
unnamed: D102.4 (DIN), D103.2 (DOUT)
unnamed: Q1.1 (B), R10.2
unnamed: Q1.3 (C), R9.1, T2.1 (G)
SD_CD: U1.19 (ELE11); also elsewhere on the board
TEMP: IC4.1 (TEMP), R32.1, X4.1
VBAT: F2.2, T1.3 (D); also elsewhere on the board
VCC: C14.1, C15.1, C18.1, D3.C, IC2.3 (IN), R9.2, T1.2 (S), T2.2 (S); also elsewhere on the board
VIBRATOR: U1.16 (ELE8); also elsewhere on the board
WS2812_DATA: D105.4 (DIN); also elsewhere on the board
WS2812_DATA_OUT: D100.2 (DOUT), X3.8 (5)
WS2812_POWER: C1.2, C2.2, C3.2, C4.2, C5.2, C6.2, C13.1, D100.1 (VDD), D101.1 (VDD), D102.1 (VDD), D103.1 (VDD), D104.1 (VDD), D105.1 (VDD), T2.3 (D), X3.2 (11); also elsewhere on the board
WS2812_POWER_EN: R10.1, U1.18 (ELE10); also elsewhere on the board

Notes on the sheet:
Voltage Regulator
Battery charger
Ideal Diode
Default: 500mA
Close jumper: 1A
GND
VBAT
Same resistance as NTC @ 25°C
SK6812 RGBW (5050 package)
Touch Controller / IO expander
Address 0x5A
IO header
SD Card power

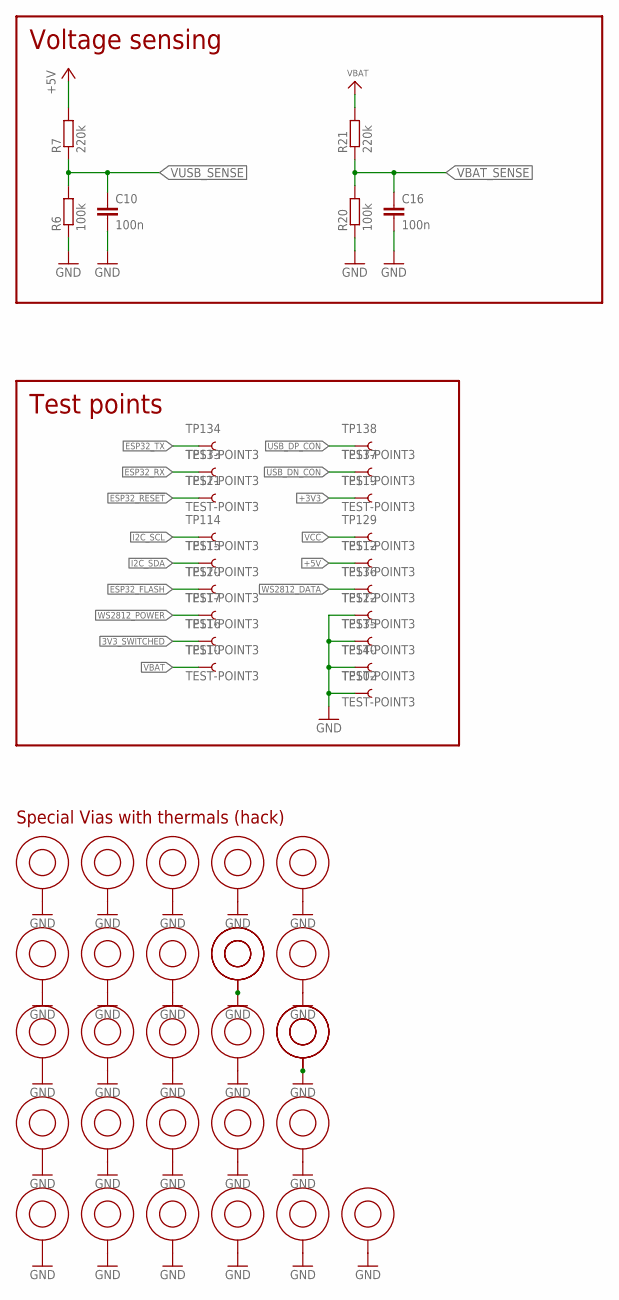
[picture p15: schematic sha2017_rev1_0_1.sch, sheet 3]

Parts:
$$U$1, $$U$2, $$U$3, $$U$4, $$U$5, $$U$6, $$U$7, $$U$8, $$U$9: VIA; PARTNO NAP
C10, C16: 100n; C0603-DASHES; PARTNO GRM188R71H104KA93D
R6, R20: 100k; R0603-DASHES; PARTNO ERJ-3GEYJ104V
R7, R21: 220k; R0603-DASHES; PARTNO ERJ-3GEYJ224V
TP102, TP110, TP112, TP114, TP115, TP116, TP117, TP119, TP120, TP121, TP122, TP129, TP133, TP134, TP135, TP136, TP137, TP138, TP140: TEST-POINT3; PAD.03X.03; PARTNO NAP
U$2, U$3, U$4, U$5, U$6, U$10, U$11, U$12, U$13, U$14, U$15, U$16, U$17, U$18, U$19, U$20, U$21, U$22, U$23: VIA; PARTNO NAP

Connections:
3V3_SWITCHED: TP116.P$1; also elsewhere on the board
+3V3: TP119.P$1; also elsewhere on the board
+5V: R7.2, TP112.P$1; also elsewhere on the board
ESP32_!RESET: TP121.P$1; also elsewhere on the board
ESP32_FLASH: TP120.P$1; also elsewhere on the board
ESP32_RX: TP133.P$1; also elsewhere on the board
ESP32_TX: TP134.P$1; also elsewhere on the board
GND: $$U$1.P$1, $$U$2.P$1, $$U$3.P$1, $$U$4.P$1, $$U$5.P$1, $$U$6.P$1, $$U$7.P$1, $$U$8.P$1, $$U$9.P$1, C10.2, C16.2, R6.1, R20.1, TP102.P$1, TP122.P$1, TP135.P$1, TP140.P$1, U$2.P$1, U$3.P$1, U$4.P$1, U$5.P$1, U$6.P$1, U$10.P$1, U$11.P$1, U$12.P$1, U$13.P$1, U$14.P$1, U$15.P$1, U$16.P$1, U$17.P$1, U$18.P$1, U$19.P$1, U$20.P$1, U$21.P$1, U$22.P$1, U$23.P$1; also elsewhere on the board
I2C_SCL: TP114.P$1; also elsewhere on the board
I2C_SDA: TP115.P$1; also elsewhere on the board
USB_DN_CON: TP137.P$1; also elsewhere on the board
USB_DP_CON: TP138.P$1; also elsewhere on the board
VBAT: R21.2, TP110.P$1; also elsewhere on the board
VBAT_SENSE: C16.1, R20.2, R21.1; also elsewhere on the board
VCC: TP129.P$1; also elsewhere on the board
VUSB_SENSE: C10.1, R6.2, R7.1; also elsewhere on the board
WS2812_DATA: TP136.P$1; also elsewhere on the board
WS2812_POWER: TP117.P$1; also elsewhere on the board

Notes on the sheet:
Special Vias with thermals (hack)
Test points
Voltage sensing

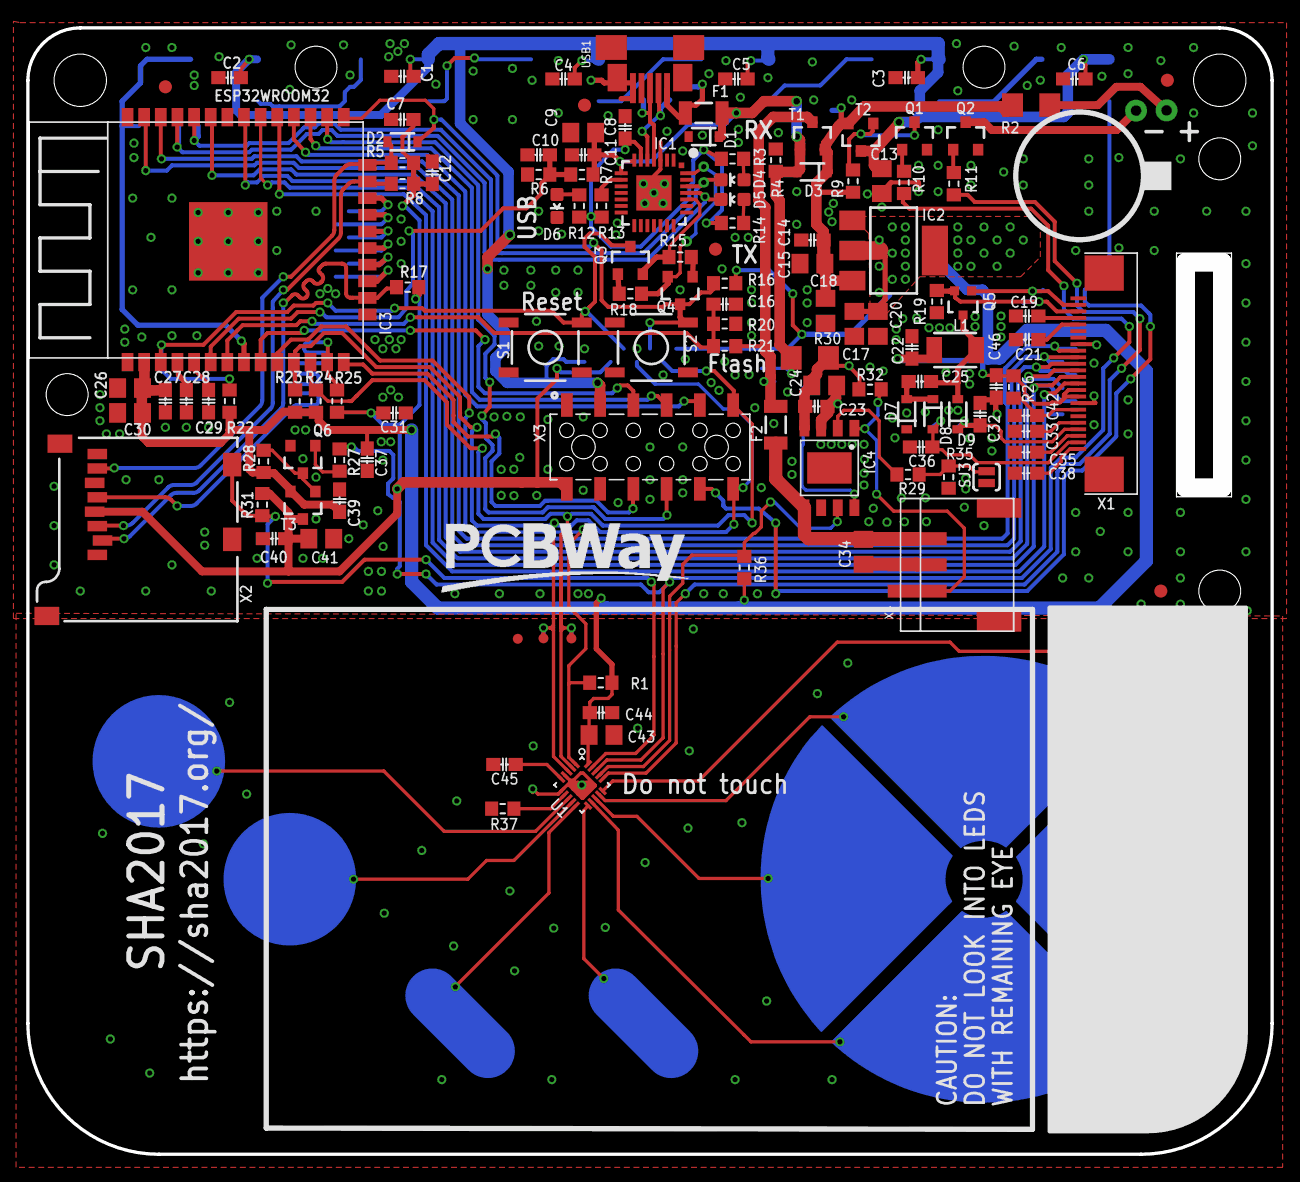
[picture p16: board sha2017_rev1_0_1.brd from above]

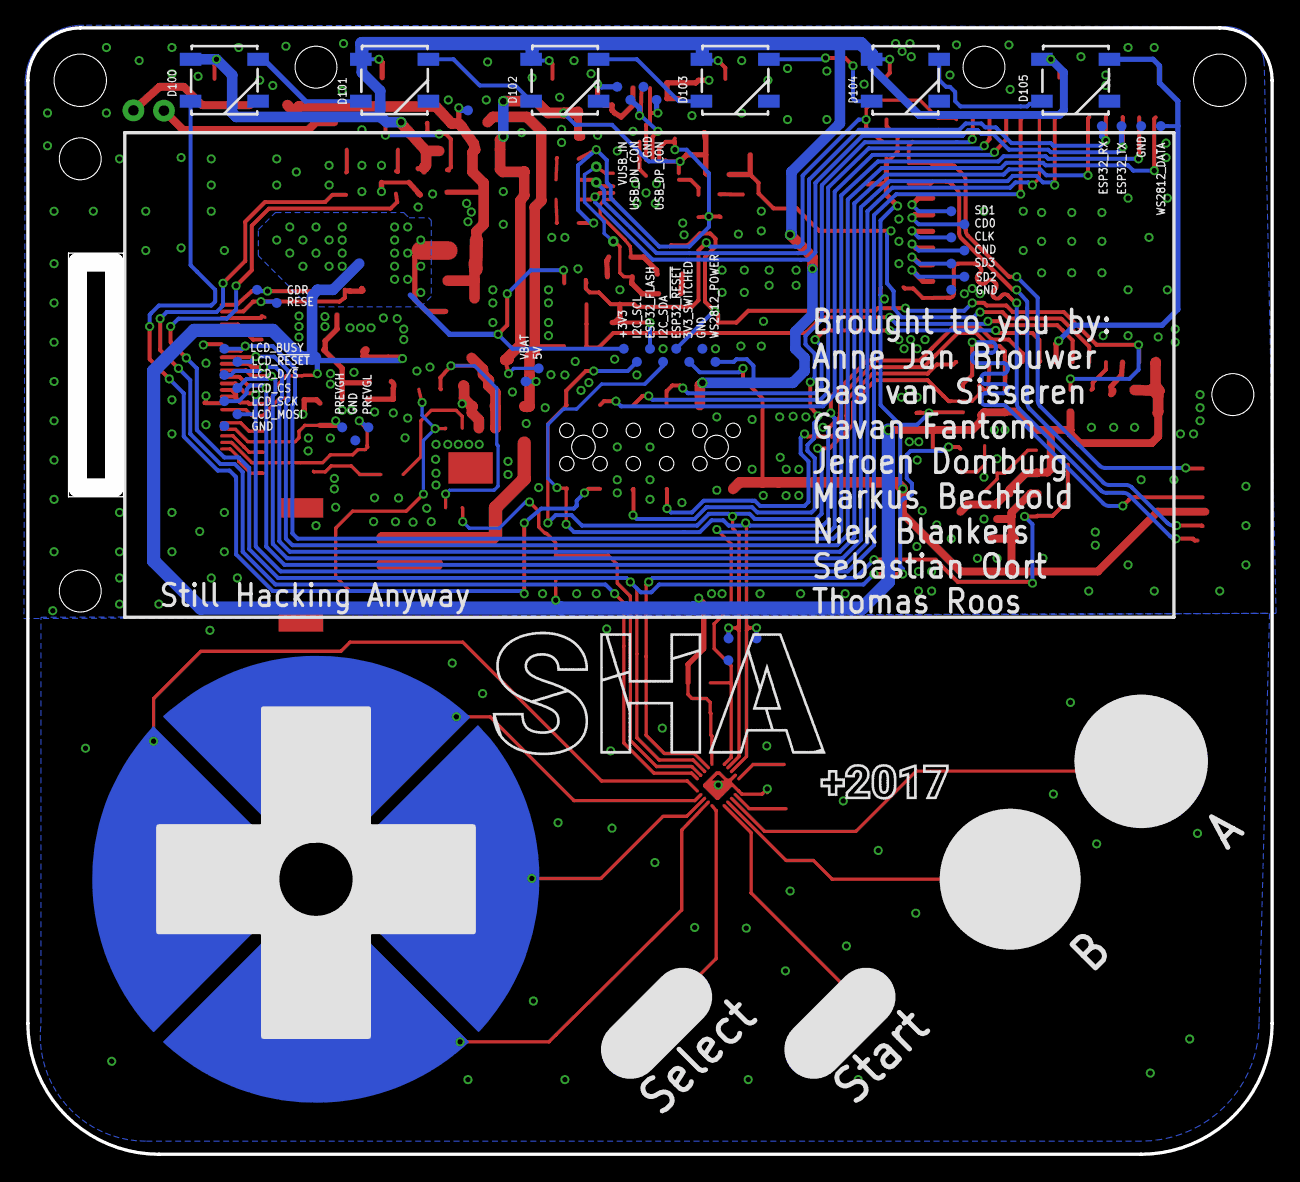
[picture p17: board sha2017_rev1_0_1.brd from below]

Board: 2 copper layers, 95.0 x 86.0 mm, 204 parts (52 on the bottom side), 96 nets.

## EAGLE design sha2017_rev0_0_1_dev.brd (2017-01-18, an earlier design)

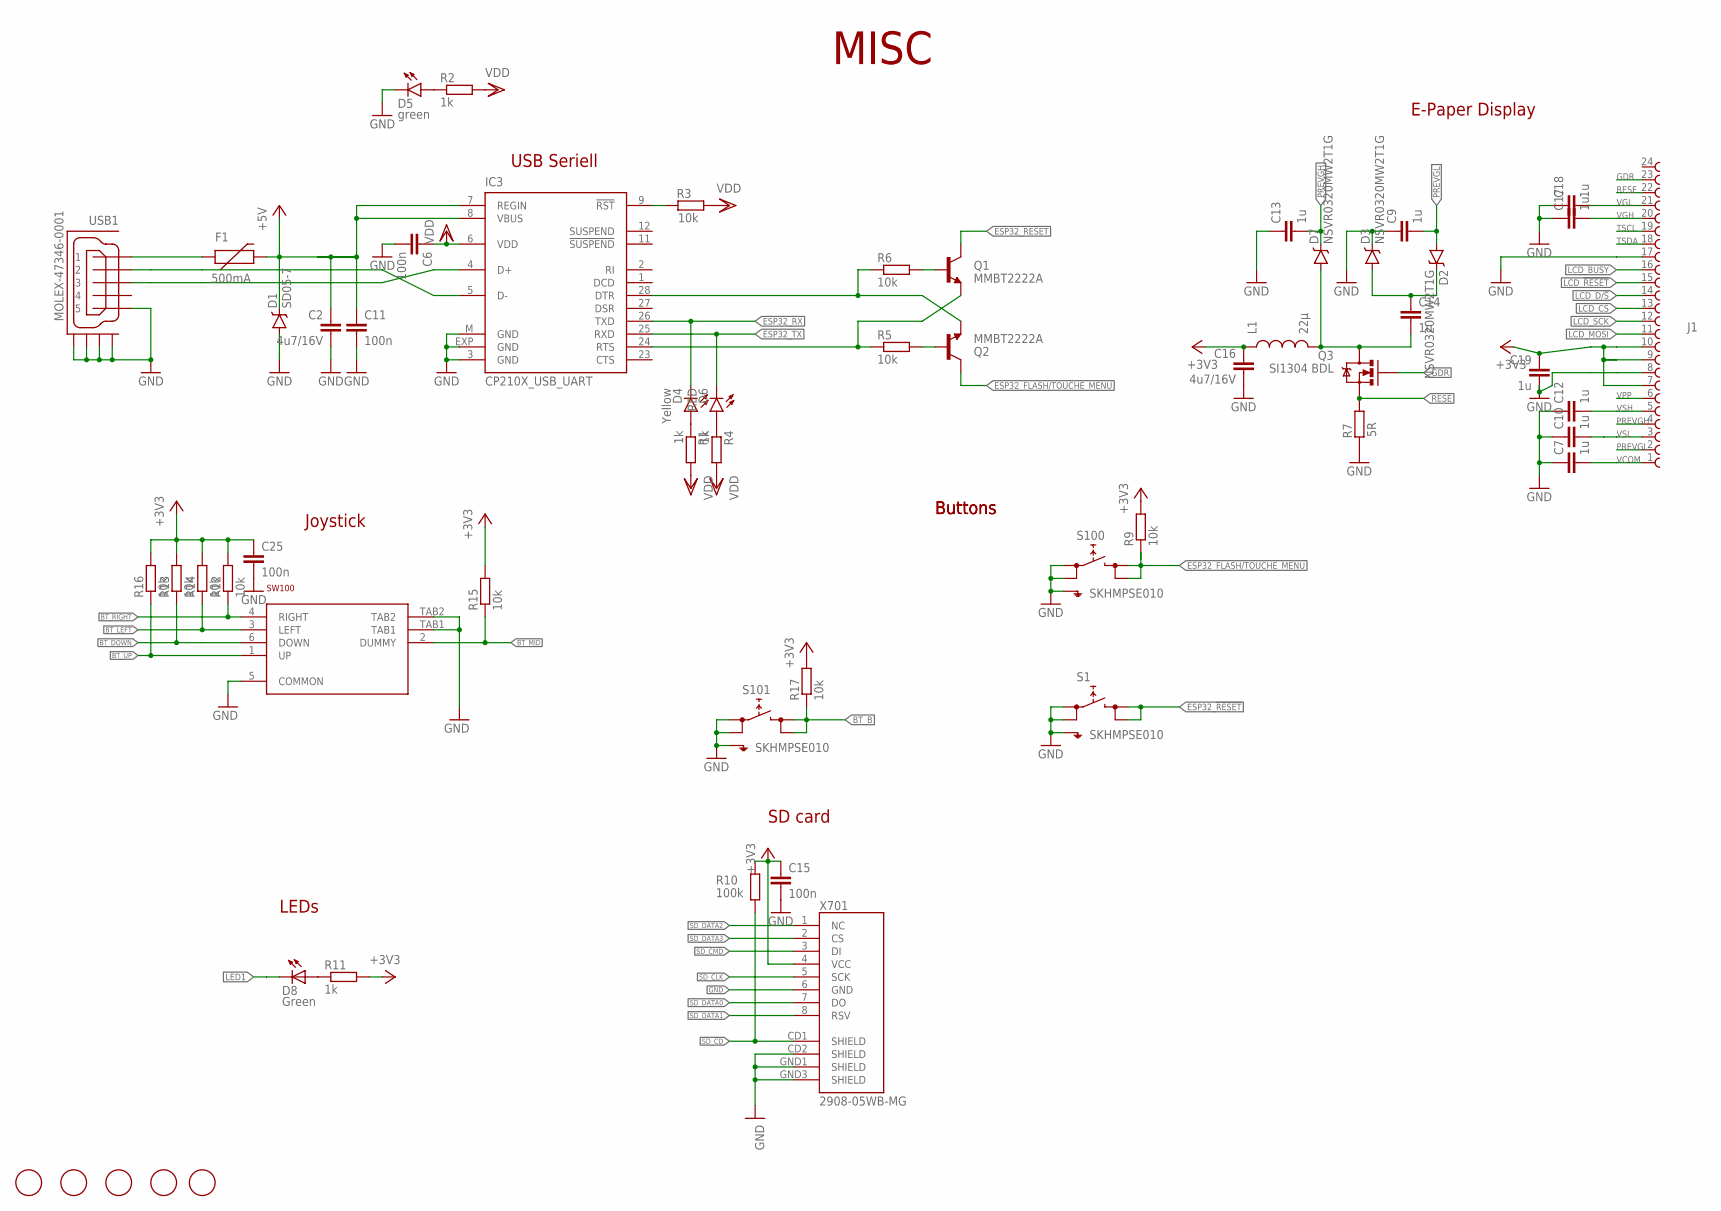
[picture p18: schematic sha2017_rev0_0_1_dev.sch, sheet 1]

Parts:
C2, C16: 4u7/16V; C0805; PARTNO GRM21BR61C475KA88K
C6, C11, C15, C25: 100n; C0603; PARTNO GRM188R71H104KA93D
C7, C9, C10, C12, C13, C14, C17, C18, C19: 1u; C0603; PARTNO GRM188R61E105KA12D
D1: SD05-7; SOD-323; PARTNO PMEG4005EJ,115
D2, D3, D7: NSVR0320MW2T1G; SOD-323; PARTNO BAT20JFILM
D4: Yellow; LED-0603
D5: green; LED-0603
D6: RED; LED-0603
D8: Green; SML1206; PARTNO 156120VS75300
F1: 500mA; PTC-1206; PARTNO 0ZCJ0025FF2E
FD1, FD2, FD3, FD4, FD5: FIDUCIAL; FIDUCIAL_1MM
IC3: CP210X_USB_UART; MLP28; PARTNO CP2102-GMR
J1: 68712414022; PARTNO 68712414022
L1: 22µ; 1210; PARTNO NLCV32T-220K-EF
Q1, Q2: MMBT2222A; SOT23-3; PARTNO BC817-25,215
Q3: SI1304 BDL; SOT323; PARTNO SI1308EDL-T1-GE3
R1, R2, R4, R11: 1k; R0603; PARTNO ERJ-3GEYJ102V
R3, R5, R6, R9, R12, R13, R14, R15, R16, R17: 10k; R0603; PARTNO ERJ-3GEYJ103V
R7: 5R; R0603-DASHES; PARTNO ERJ-3GEYJ5R1V
R10: 100k; R0603; PARTNO CRCW0603100KFKEA
S1, S100, S101: SKHMPSE010; SKHMPXE010; PARTNO SKHMQME010
SW100: MCMT5-F-V; PARTNO SKRHAAE010
USB1: MOLEX-47346-0001; MOLEX-47364-0001; PARTNO 10118194-0001LF
X701: 2908-05WB-MG; MICRO-SD-SOCKET-PP; PARTNO 2908-05WB-MG

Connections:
+3V3: C15.1, C16.1, C19.1, C25.1, J1.7, J1.9, J1.10, L1.1, R9.2, R10.1, R11.2, R12.2, R13.2, R14.2, R15.2, R16.2, R17.2, X701.4 (VCC); also elsewhere on the board
+5V: C2.1, C11.1, D1.C, F1.2, IC3.7 (REGIN), IC3.8 (VBUS); also elsewhere on the board
BT_B: R17.1, S101.3 (2.1), S101.4 (2.2); also elsewhere on the board
BT_DOWN: R13.1, SW100.6 (DOWN); also elsewhere on the board
BT_LEFT: R14.1, SW100.3 (LEFT); also elsewhere on the board
BT_MID: R15.1, SW100.2 (DUMMY); also elsewhere on the board
BT_RIGHT: R12.1, SW100.4 (RIGHT); also elsewhere on the board
BT_UP: R16.1, SW100.1 (UP); also elsewhere on the board
ESP32_!RESET: Q1.3 (C), S1.3 (2.1), S1.4 (2.2); also elsewhere on the board
ESP32_FLASH/TOUCHE_MENU: Q2.3 (C), R9.1, S100.3 (2.1), S100.4 (2.2); also elsewhere on the board
ESP32_RX: D4.C, IC3.26 (TXD); also elsewhere on the board
ESP32_TX: D6.C, IC3.25 (RXD); also elsewhere on the board
GDR: J1.23, Q3.1 (G)
GND: C2.2, C6.2, C7.1, C9.1, C10.1, C11.2, C12.1, C13.1, C15.2, C16.2, C17.1, C18.1, C19.2, C25.2, D1.A, D3.C, D5.C, IC3.3 (GND), IC3.EXP (GND), IC3.M (GND), J1.8, J1.17, R7.2, S1.1 (1.1), S1.2 (1.2), S1.5 (SH), S100.1 (1.1), S100.2 (1.2), S100.5 (SH), S101.1 (1.1), S101.2 (1.2), S101.5 (SH), SW100.5 (COMMON), SW100.TAB1, SW100.TAB2, USB1.5, USB1.GND1, USB1.GND2, USB1.GND3, USB1.GND4, X701.6 (GND), X701.CD2 (SHIELD), X701.GND1 (SHIELD), X701.GND3 (SHIELD); also elsewhere on the board
LCD_!RESET: J1.15; also elsewhere on the board
LCD_BUSY: J1.16; also elsewhere on the board
LCD_CS: J1.13; also elsewhere on the board
LCD_D/!S: J1.14; also elsewhere on the board
LCD_MOSI: J1.11; also elsewhere on the board
LCD_SCK: J1.12; also elsewhere on the board
LED1: D8.C; also elsewhere on the board
unnamed: IC3.9 (!RST), R3.2
unnamed: IC3.24 (RTS), Q1.2 (E), R5.1
unnamed: IC3.28 (DTR), Q2.2 (E), R6.1
unnamed: Q2.1 (B), R5.2
unnamed: Q1.1 (B), R6.2
unnamed: C14.1, D2.C, D3.A
unnamed: C14.2, D7.A, L1.2, Q3.3 (D)
unnamed: D8.A, R11.1
unnamed: D5.A, R2.1
unnamed: D4.A, R1.1
unnamed: D6.A, R4.1
unnamed: F1.1, USB1.1
PREVGH: C13.2, D7.C, J1.4
PREVGL: C9.2, D2.A, J1.2
RESE: J1.22, Q3.2 (S), R7.1
SD_CD: R10.2, X701.CD1 (SHIELD); also elsewhere on the board
SD_CLK: X701.5 (SCK); also elsewhere on the board
SD_CMD: X701.3 (DI); also elsewhere on the board
SD_DATA0: X701.7 (DO); also elsewhere on the board
SD_DATA1: X701.8 (RSV); also elsewhere on the board
SD_DATA2: X701.1 (NC); also elsewhere on the board
SD_DATA3: X701.2 (CS); also elsewhere on the board
TSCL: J1.19
TSDA: J1.18
USB_DN_CON: IC3.5 (D-), USB1.2
USB_DP_CON: IC3.4 (D+), USB1.3
VCOM: C7.2, J1.1
VDD: C6.1, IC3.6 (VDD), R1.2, R2.2, R3.1, R4.2
VGH: C17.2, J1.20
VGL: C18.2, J1.21
VPP: J1.6
VSH: C12.2, J1.5
VSL: C10.2, J1.3

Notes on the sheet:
MISC
USB Seriell
E-Paper Display
Joystick
Buttons
LEDs
SD card

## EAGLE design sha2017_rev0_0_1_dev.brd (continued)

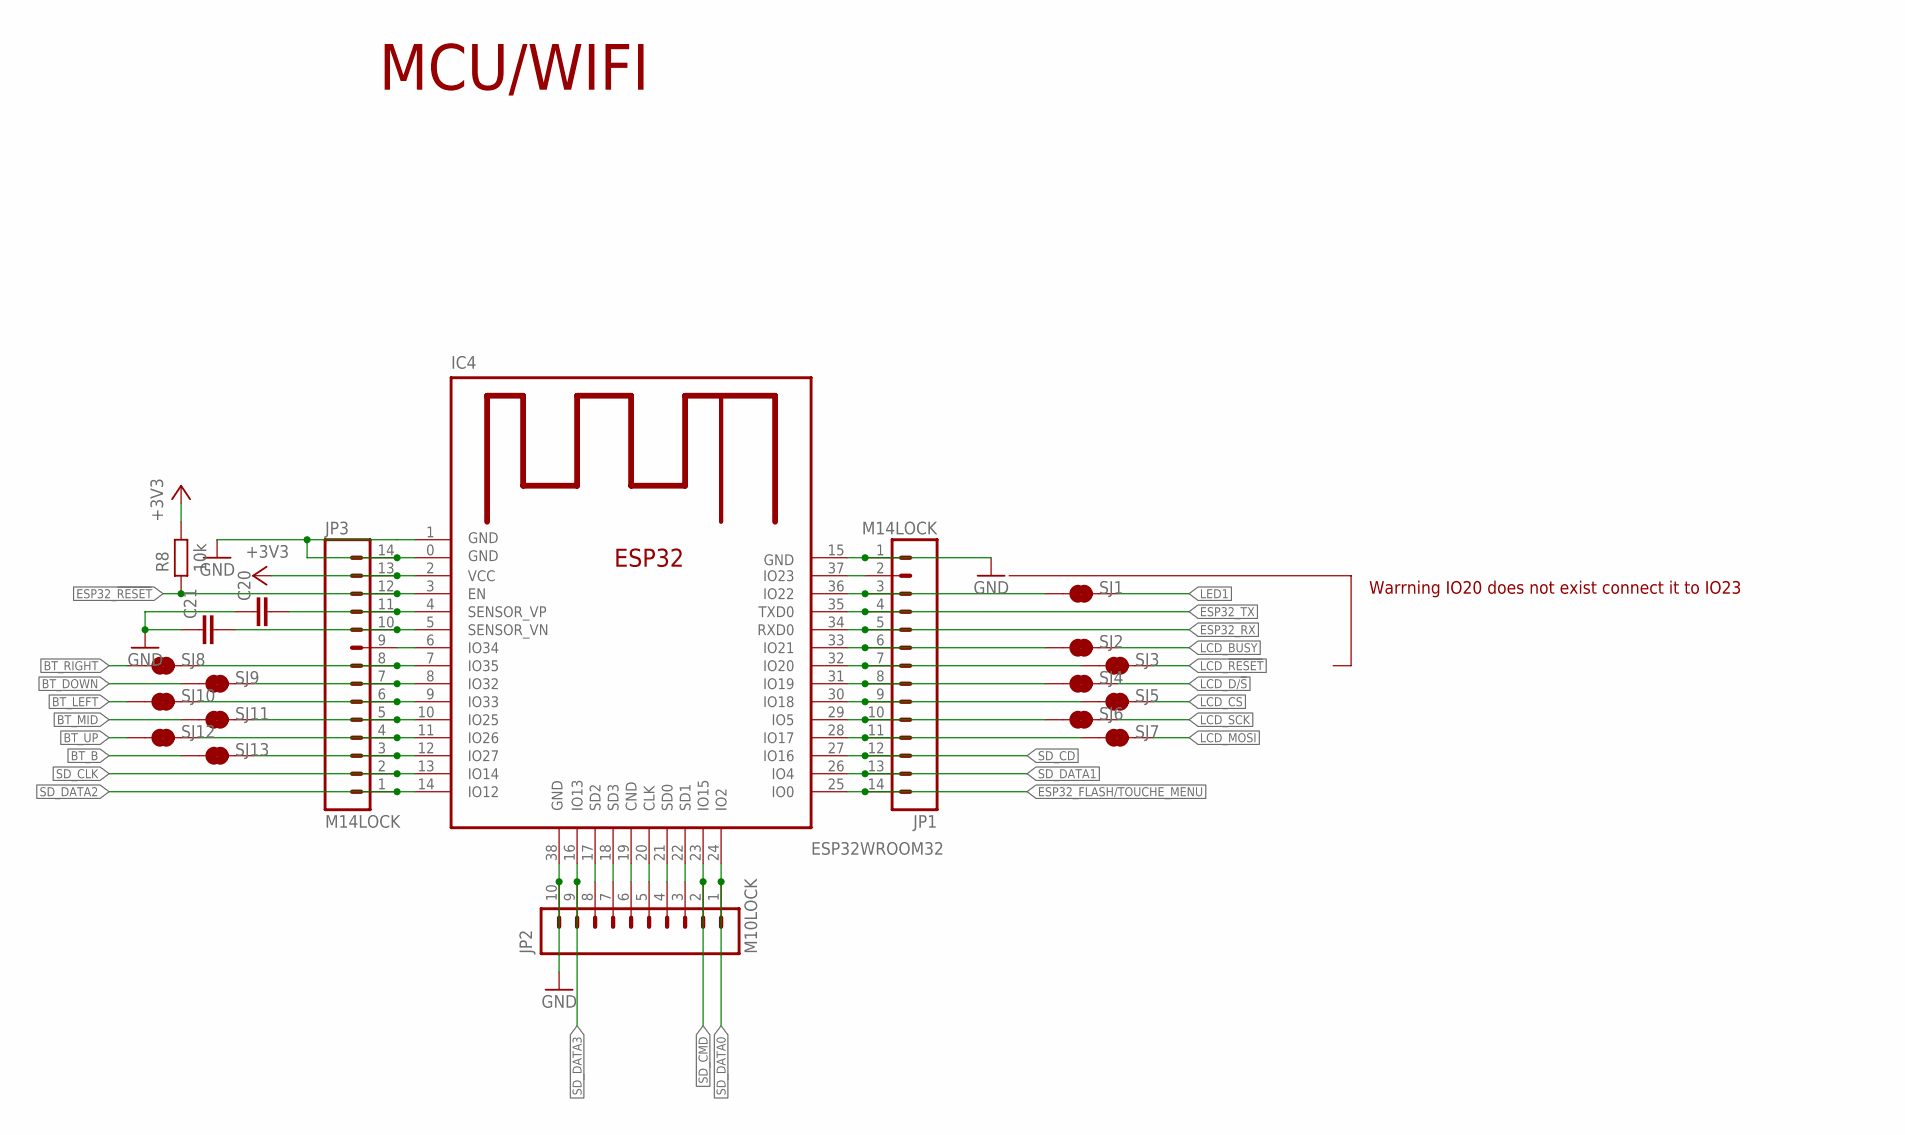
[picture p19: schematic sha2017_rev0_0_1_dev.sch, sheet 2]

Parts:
C20, C21: C-EUC0603; C0603
IC4: ESP32WROOM32; ESP32MOD
JP1, JP3: M14LOCK; 1X14_LOCK
JP2: M10LOCK; 1X10_LOCK
R8: 10k; R0603; PARTNO ERJ-3GEYJ103V
SJ1, SJ2, SJ3, SJ4, SJ5, SJ6, SJ7, SJ8, SJ9, SJ10, SJ11, SJ12, SJ13: JUMPER-PAD-2-NC_BY_TRACE; PAD-JUMPER-2-NC_BY_TRACE_YES_SILK

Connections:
+3V3: IC4.2 (VCC), JP3.13, R8.1; also elsewhere on the board
BT_B: SJ13.1; also elsewhere on the board
BT_DOWN: SJ9.1; also elsewhere on the board
BT_LEFT: SJ10.1; also elsewhere on the board
BT_MID: SJ11.1; also elsewhere on the board
BT_RIGHT: SJ8.1; also elsewhere on the board
BT_UP: SJ12.1; also elsewhere on the board
ESP32_!RESET: IC4.3 (EN), JP3.12, R8.2; also elsewhere on the board
ESP32_FLASH/TOUCHE_MENU: IC4.25 (IO0), JP1.14; also elsewhere on the board
ESP32_RX: IC4.34 (RXD0), JP1.5; also elsewhere on the board
ESP32_TX: IC4.35 (TXD0), JP1.4; also elsewhere on the board
GND: C20.1, C21.1, IC4.0 (GND), IC4.1 (GND), IC4.15 (GND), IC4.38 (GND), JP1.1, JP2.10, JP3.14; also elsewhere on the board
LCD_!RESET: SJ3.2; also elsewhere on the board
LCD_BUSY: SJ2.2; also elsewhere on the board
LCD_CS: SJ5.2; also elsewhere on the board
LCD_D/!S: SJ4.2; also elsewhere on the board
LCD_MOSI: SJ7.2; also elsewhere on the board
LCD_SCK: SJ6.2; also elsewhere on the board
LED1: SJ1.2; also elsewhere on the board
unnamed: IC4.6 (IO34), JP3.9
unnamed: IC4.17 (SD2), JP2.8
unnamed: IC4.18 (SD3), JP2.7
unnamed: IC4.19 (CND), JP2.6
unnamed: IC4.20 (CLK), JP2.5
unnamed: IC4.21 (SD0), JP2.4
unnamed: IC4.22 (SD1), JP2.3
unnamed: IC4.37 (IO23), JP1.2
unnamed: IC4.36 (IO22), JP1.3, SJ1.1
unnamed: IC4.33 (IO21), JP1.6, SJ2.1
unnamed: IC4.32 (IO20), JP1.7, SJ3.1
unnamed: IC4.30 (IO18), JP1.9, SJ5.1
unnamed: IC4.29 (IO5), JP1.10, SJ6.1
unnamed: IC4.28 (IO17), JP1.11, SJ7.1
unnamed: C20.2, IC4.4 (SENSOR_VP), JP3.11
unnamed: C21.2, IC4.5 (SENSOR_VN), JP3.10
unnamed: IC4.7 (IO35), JP3.8, SJ8.2
unnamed: IC4.8 (IO32), JP3.7, SJ9.2
unnamed: IC4.9 (IO33), JP3.6, SJ10.2
unnamed: IC4.10 (IO25), JP3.5, SJ11.2
unnamed: IC4.11 (IO26), JP3.4, SJ12.2
unnamed: IC4.12 (IO27), JP3.3, SJ13.2
unnamed: IC4.31 (IO19), JP1.8, SJ4.1
SD_CD: IC4.27 (IO16), JP1.12; also elsewhere on the board
SD_CLK: IC4.13 (IO14), JP3.2; also elsewhere on the board
SD_CMD: IC4.23 (IO15), JP2.2; also elsewhere on the board
SD_DATA0: IC4.24 (IO2), JP2.1; also elsewhere on the board
SD_DATA1: IC4.26 (IO4), JP1.13; also elsewhere on the board
SD_DATA2: IC4.14 (IO12), JP3.1; also elsewhere on the board
SD_DATA3: IC4.16 (IO13), JP2.9; also elsewhere on the board

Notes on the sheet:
MCU/WIFI
Warrning IO20 does not exist connect it to IO23

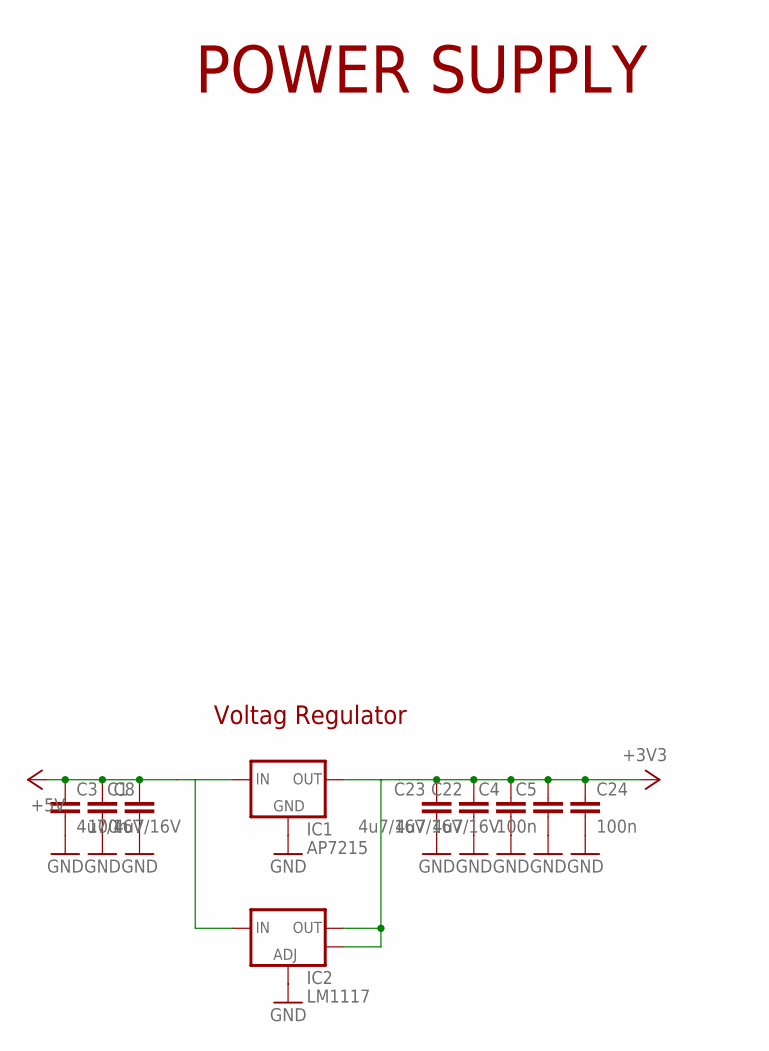
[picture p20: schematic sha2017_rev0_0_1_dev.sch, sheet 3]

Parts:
C1, C5, C24: 100n; C0603; PARTNO GRM188R71H104KA93D
C3, C4, C8, C22, C23: 4u7/16V; C0805; PARTNO GRM21BR61C475KA88K
IC1: AP7215; SOT89; PARTNO AP7215-33YG-13
IC2: LM1117; SOT223; PARTNO LM1117MPX-3.3/NOPB

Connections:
+3V3: C4.1, C5.1, C22.1, C23.1, C24.1, IC1.3 (OUT), IC2.2 (OUT), IC2.4 (OUT); also elsewhere on the board
+5V: C1.1, C3.1, C8.1, IC1.2 (IN), IC1.2@ (IN), IC2.3 (IN); also elsewhere on the board
GND: C1.2, C3.2, C4.2, C5.2, C8.2, C22.2, C23.2, C24.2, IC1.1 (GND), IC2.1 (ADJ); also elsewhere on the board

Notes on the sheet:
Voltag Regulator
POWER SUPPLY

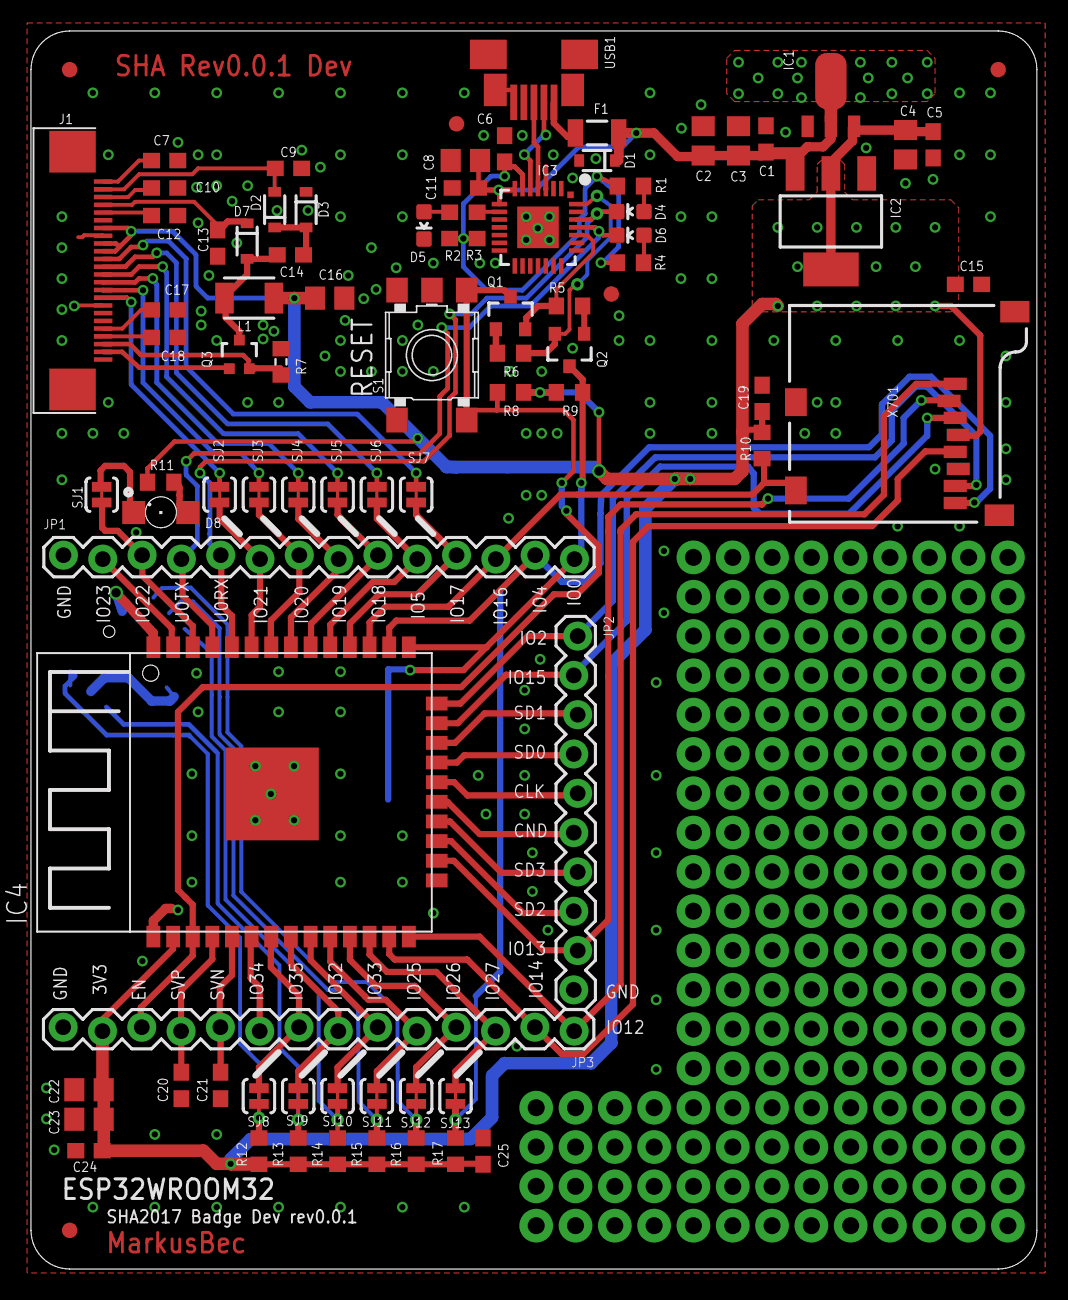
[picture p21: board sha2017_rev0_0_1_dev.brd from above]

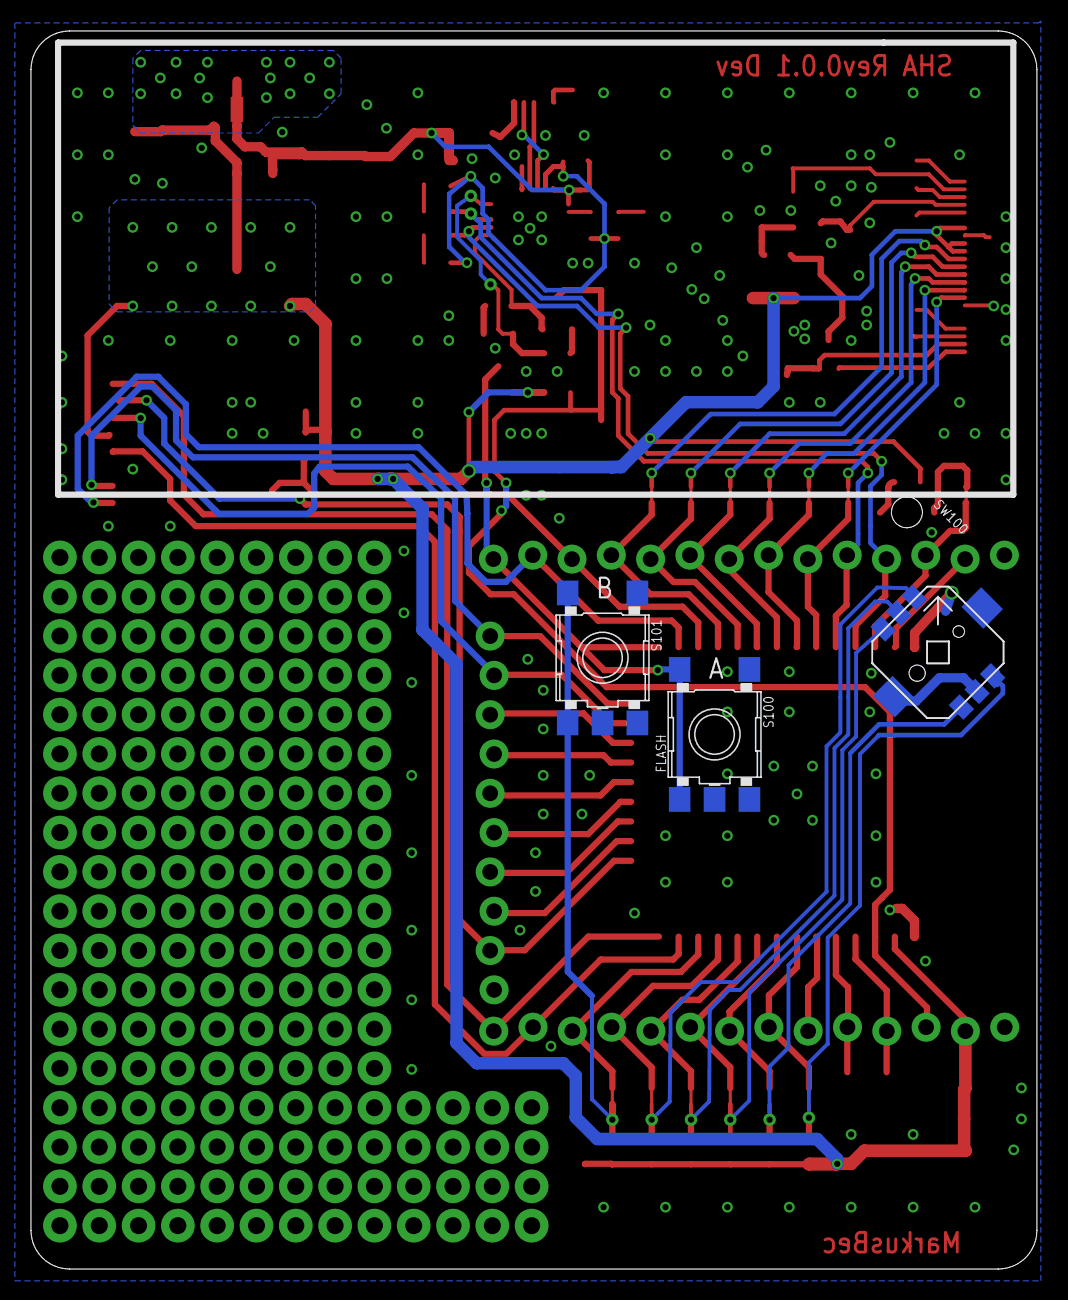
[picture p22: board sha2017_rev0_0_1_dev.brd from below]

Board: 2 copper layers, 65.0 x 80.0 mm, 87 parts (3 on the bottom side), 74 nets.

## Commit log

2016-09-14 initial beta Schematics
    [sha2017_rev0.1.sch]
2016-09-14 add esp32 pinout
    [sha2017_rev0.1.sch]
2016-09-14 schematic Cleanup adding MPU6050
    [sha2017_rev0.1.sch]
2016-09-21 minimal Dev version to verify the e-paper display
    [sha2017_rev0_1_1_dev.sch]
2016-09-21 Moved files around
    [sha2017_rev0.1.sch, sha2017_rev0_1_dev.sch]
2016-09-21 add pinout for the lcd added usb status leds
    [sha2017_rev0_1_1_dev.sch]
2016-09-22 initial PCB design
    [sha2017_rev0_1_dev.brd, sha2017_rev0_1_dev.sch]
2016-09-22 removed dedicated flash switch, switch A will be now flash and switch A.
    [sha2017_rev0_1_dev.brd, sha2017_rev0_1_dev.sch]
2016-09-22 all parts places minor adjustments needed
    [sha2017_rev0_1_dev.brd, sha2017_rev0_1_dev.sch]
2016-09-23 finished routing. Part designators needs to be fixed
    [sha2017_rev0_1_dev.brd, sha2017_rev0_1_dev.sch]
2016-09-23 fixed all part designators
    [sha2017_rev0_1_dev.brd, sha2017_rev0_1_dev.sch]
2016-09-24 some PCB tweeking
    [sha2017_rev0_1_dev.brd, sha2017_rev0_1_dev.sch]
2016-10-17 changed ESP module to WROOM32
    [sha2017_rev0_1_dev.brd, sha2017_rev0_1_dev.sch]
2016-10-17 fixed silkscreen
    [sha2017_rev0_1_dev.brd, sha2017_rev0_1_dev.sch]
2016-10-18 Added text
    [sha2017_rev0_1_dev.brd]
2016-10-19 added markings
    [sha2017_rev0_1_dev.brd]
2016-10-25 add gerber produktion data
    [sha2017_rev0_1_dev Kopie.sch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]
2016-12-01 Swapped NC and IO23
    [sha2017_rev0_1_dev.brd, sha2017_rev0_1_dev.sch]
2016-12-01 Bumped version
    [sha2017_rev0_0_2_dev.brd, sha2017_rev0_0_2_dev.sch]
2017-01-18 Produktion Version of the first badge prototyp
    errata
    IO20 does not exsist
    Connect it to IO23
    [sha2017_rev0_0_1_dev.brd, sha2017_rev0_0_1_dev.sch]
2017-01-18 Initial Commit Of Version 0.1.0
    First full funktional Prototyp with battery and charger.
    Still some routing work to do.
    [sha2017_rev0_1_0_dev.brd, sha2017_rev0_1_0_dev.sch]
2017-01-21 placed most of the parts
    [sha2017_rev0_1_0_dev.brd, sha2017_rev0_1_0_dev.sch]
2017-01-25 finised routing
    [sha2017_rev0_1_0_dev.brd, sha2017_rev0_1_0_dev.sch]
2017-01-25 removed some drc errors and add feducials
    [sha2017_rev0_1_0_dev.brd]
2017-01-25 add spezial vias to touch arrea to trick DRC
    [sha2017_rev0_1_0_dev.brd, sha2017_rev0_1_0_dev.sch]
2017-01-26 added most of the test points
    [sha2017_rev0_1_0_dev.brd, sha2017_rev0_1_0_dev.sch]
2017-01-26 renumbered PCB and placed designators
    [sha2017_rev0_1_0_dev.brd, sha2017_rev0_1_0_dev.sch]
2017-01-26 added SDIO pullups and some bootstrap magic for it
    [sha2017_rev0_1_0_dev.brd, sha2017_rev0_1_0_dev.sch]
2017-01-26 replaced transistor with a diode becaus we need it non inverting
    [sha2017_rev0_1_0_dev.brd, sha2017_rev0_1_0_dev.sch]
2017-01-26 add solder briges to unused IOs at 1 Wire SDiomode (roosted: MIMIMI I WANT MORE IOS!!!!!)
    [sha2017_rev0_1_0_dev.brd, sha2017_rev0_1_0_dev.sch]
2017-01-26 fixed designators
    [sha2017_rev0_1_0_dev.brd, sha2017_rev0_1_0_dev.sch]
2017-01-27 some small fixes
    [sha2017_rev0_1_0_dev.brd, sha2017_rev0_1_0_dev.sch]
2017-01-27 cleanup an Testpoint marking
    [sha2017_rev0_1_0_dev.brd, sha2017_rev0_1_0_dev.sch]
2017-01-28 add 1 LED
    [sha2017_rev0_1_0_dev.brd, sha2017_rev0_1_0_dev.sch]
2017-01-30 add initial BOM
2017-01-30 adjusted values and add moe coper to the charger region
    [sha2017_rev0_1_0_dev.brd, sha2017_rev0_1_0_dev.sch]
2017-01-30 MOOOOOOOORRRRREEEEEEE VIAS for the charger
    [sha2017_rev0_1_0_dev.brd]
2017-01-30 fixed bug at powersupply Mosfets was N channel and need to be P channel to switch the Highside voltage
    [sha2017_rev0_1_0_dev.brd, sha2017_rev0_1_0_dev.sch]
2017-01-30 fixed pinswap at sd card
    [sha2017_rev0_1_0_dev.brd, sha2017_rev0_1_0_dev.sch]
2017-01-30 changes via styl for net DATA1
    [sha2017_rev0_1_0_dev.brd]
2017-01-30 added 4,7µF decopling capacitor to the cpt112s power rails
    [sha2017_rev0_1_0_dev.brd, sha2017_rev0_1_0_dev.sch]
2017-01-30 minor adjustments
    [sha2017_rev0_1_0_dev.brd]
2017-01-30 SD pullups to 3V3_SWITCHED
    [sha2017_rev0_1_0_dev.brd, sha2017_rev0_1_0_dev.sch]
2017-01-30 Added some artwork
    [sha2017_rev0_1_0_dev.brd]
2017-01-30 fixing broken ground plane
    [sha2017_rev0_1_0_dev.brd, sha2017_rev0_1_0_dev.sch]
2017-01-31 Removed intermediate dimensions, added PDF
    [sha2017_rev0_1_0_dev.brd]
2017-01-31 add some color
    [sha2017_rev0_1_0_dev.brd, sha2017_rev0_1_0_dev.sch]
2017-01-31 add missin ground via at cpt112 programming interface
    [sha2017_rev0_1_0_dev.brd, sha2017_rev0_1_0_dev.sch]
2017-02-01 Design Freeze
    [sha2017_rev0_1_0_dev.GBL, sha2017_rev0_1_0_dev.GBO, sha2017_rev0_1_0_dev.GBP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]
2017-04-07 fixed some values
    [sha2017_rev0_1_0_dev.brd, sha2017_rev0_1_0_dev.sch]
2017-04-07 some more changes
    [sha2017_rev0_1_0_dev.brd, sha2017_rev0_1_0_dev.sch]
2017-04-23 Reorganize gerber
    [sha2017_rev0_1_dev Kopie.sch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]
2017-04-23 Replace charge controller, cleaned up schematic
    [sha2017_rev1_0_0.brd, sha2017_rev1_0_0.sch]
2017-04-24 Swap port expander and CPT112S for MPR121
    [sha2017_rev1_0_0.brd, sha2017_rev1_0_0.sch]
2017-04-24 Replace BJTs by AO3400 nFET
    [sha2017_rev1_0_0.brd, sha2017_rev1_0_0.sch]
2017-04-24 Fix r10
    [sha2017_rev1_0_0.sch]
2017-04-25 Removed unnecessary MOSFETs
    [sha2017_rev1_0_0.brd, sha2017_rev1_0_0.sch]
2017-04-26 Finalized LED and SD card power switches, rerouted
    [sha2017_rev1_0_0.brd, sha2017_rev1_0_0.sch]
2017-04-26 Reroute touch controller
    [sha2017_rev1_0_0.brd, sha2017_rev1_0_0.sch]
2017-04-27 Reverted power switches, re-routed touch controller
    [sha2017_rev0_1_dev Kopie.sch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]
2017-04-27 Fix schematic
    [sha2017_rev1_0_0.sch]
2017-04-27 Fix airwire
    [sha2017_rev1_0_0.brd]
2017-04-27 MarkusBec rerouting and fixes
    [sha2017_rev1_0_0.brd, sha2017_rev1_0_0.sch]
2017-04-27 Board change
    [sha2017_rev1_0_0.brd]
2017-04-27 Center trace
    [sha2017_rev1_0_0.brd]
2017-04-27 R2 0603->1206
    [sha2017_rev1_0_0.brd, sha2017_rev1_0_0.sch]
2017-04-27 Extra vreg (not routed\!)
    [sha2017_rev1_0_0.brd, sha2017_rev1_0_0.sch]
2017-04-27 Replace vreg
    [sha2017_rev1_0_0.brd, sha2017_rev1_0_0.sch]
2017-04-27 Gerbers, design freeze
    [sha2017_rev1_0_0.GBL, sha2017_rev1_0_0.GBO, sha2017_rev1_0_0.GBP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]
2017-05-06 Update README with new board version
2017-05-07 Fix short, add silkscreen logo
    [sha2017_rev1_0_1.brd, sha2017_rev1_0_1.sch]
2017-05-07 Fixed DRU Fixed routing adjust lables and increase size
    [sha2017_rev1_0_1.brd]
2017-05-07 rerout extio-4 and added register holes ext socket
    [sha2017_rev1_0_1.brd]
2017-05-07 some fixes
    [sha2017_rev1_0_1.brd]
2017-05-08 Add option for GD/DKE displays - TODO: ROUTE
    [sha2017_rev1_0_1.brd, sha2017_rev1_0_1.sch]
2017-05-08 routing of display option
    [sha2017_rev1_0_1.brd, sha2017_rev1_0_1.sch]
2017-05-18 FINAL gerbers, design freeze
    [sha2017_rev1_0_1.brd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]
2017-05-27 Panel gerbers
2017-06-09 Add assembly component drawing
2017-06-14 small proto board for the sha badge
    [sha2017_proto_rev1_0_0.brd, sha2017_proto_rev1_0_0.sch]
2017-07-15 add rev0.0.2 schematic pdf
2017-08-23 Add final BOM
    [sha2017_rev1_0_1_bom.ods]

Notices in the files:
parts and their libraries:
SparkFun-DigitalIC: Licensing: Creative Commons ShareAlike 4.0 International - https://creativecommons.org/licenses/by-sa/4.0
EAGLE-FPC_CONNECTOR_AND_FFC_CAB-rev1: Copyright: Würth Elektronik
